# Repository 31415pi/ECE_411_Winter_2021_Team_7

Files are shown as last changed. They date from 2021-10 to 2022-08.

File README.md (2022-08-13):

# ECE411 Sunrise Alarm Clock - Team 7
,
> "Never wake-up in darkness..."

Actual project completion utilized a completely different set of hardware. Updates forthcoming. The Sunrise Alarm Clock is an add on board for an arduino which allows users to interact with an OLED display clock using guestures. The board features 12 RGB SMD LEDs which are used to display time in a meaningful way, indicate confirmation of guesture input, and provide an illuminated alarm experience. A buzzer along with two analog buttons are included to facilitate traditional inputs and alarms if necessary. 

View the [Product Design Specification](./Product%20Design%20Specification%20v1.pdf) for more information.

Look at the [Project Board](https://github.com/31415pi/ECE_411_Winter_2021_Team_7/projects/1).

Schematic located at [Hardware/Schematic](./Hardware/Schematic.pdf).

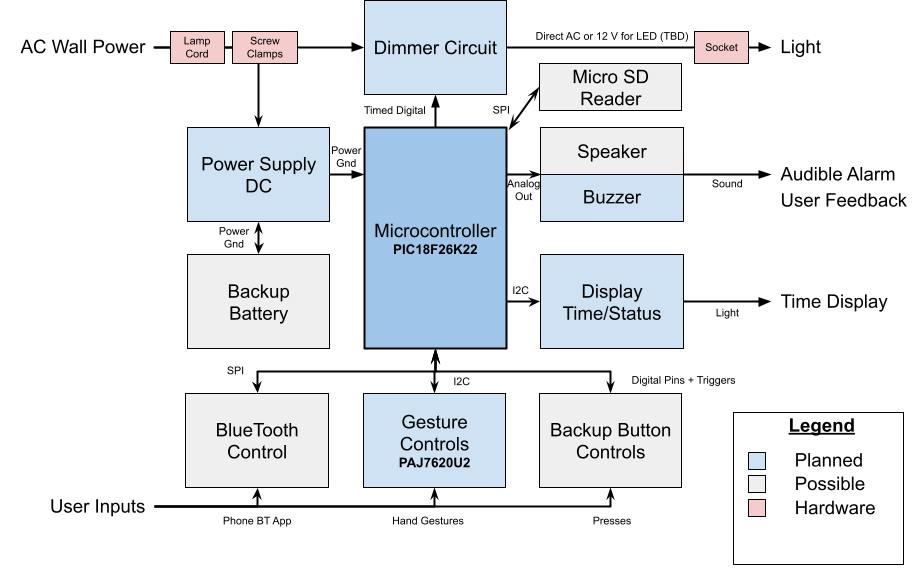
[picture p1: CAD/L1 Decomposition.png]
L1 Decomposition


## Parts List

Parts list on [google drive](https://docs.google.com/spreadsheets/d/1yFu2dnekZCLbKxV9tUKsMTaaS4XpjHtpUTBXEi358RU/edit#gid=0). [Convert to Markdown](https://tabletomarkdown.com/convert-spreadsheet-to-markdown/).

| Part (datasheet link) | Name | Type | Notes | Datasheet | Website | Source | Price  |
| --- | --- | --- | --- | --- | --- | --- | --- |
| [HT16K33](https://github.com/31415pi/ECE_411_Winter_2021_Team_7/blob/main/Datasheets/HT16K33v120(LEDcontroller).pdf) | RAM Mapping 16\*8 LED Controller Driver with keyscan | LED Controller  | | | [https://www.holtek.com/productdetail/-/vg/16K33](https://www.holtek.com/productdetail/-/vg/16K33) | | |
| [PIC18F26K42](https://github.com/31415pi/ECE_411_Winter_2021_Team_7/blob/main/Datasheets/PIC18(L)F26-27-45-46-47-55-56-57K42-Data-Sheet-40001919G.pdf) | | Microcontroller | Actual Model Read from Chip. | [https://www.microchip.com/content/dam/mchp/documents/MCU08/ProductDocuments/DataSheets/PIC18(L)F26-27-45-46-47-55-56-57K42-Data-Sheet-40001919G.pdf](https://www.microchip.com/content/dam/mchp/documents/MCU08/ProductDocuments/DataSheets/PIC18(L)F26-27-45-46-47-55-56-57K42-Data-Sheet-40001919G.pdf) | [https://www.microchip.com/en-us/product/PIC18F26K42](https://www.microchip.com/en-us/product/PIC18F26K42) | EPL | $ 1.50 |
| [IRM-05-5](https://github.com/31415pi/ECE_411_Winter_2021_Team_7/blob/main/Datasheets/IRM-05(ac-5vsupply).pdf) | | DC Power Supply | | | | [Mouser](https://www.mouser.com/ProductDetail/709-IRM05-5) | $ 8.81 |
| [MOC3052TVM](https://github.com/31415pi/ECE_411_Winter_2021_Team_7/blob/main/Datasheets/MOC3052M(ACcont).pdf) | | AC Controller | | | | [Mouser](https://www.mouser.com/ProductDetail/512-MOC3052SR2M)  | $ 1.15 |
| [ACST410-8BTR](https://github.com/31415pi/ECE_411_Winter_2021_Team_7/blob/main/Datasheets/ACST410(ACswitch).pdf) | | AC Switch | | | | [Mouser](https://www.mouser.com/ProductDetail/511-ACST410-8BTR) | $ 0.85 |
| [SFH628A](https://github.com/31415pi/ECE_411_Winter_2021_Team_7/blob/main/Datasheets/SFH628A(ACsensor).pdf) | | AC Sensor | | | | [Mouser](https://www.mouser.com/ProductDetail/782-SFH6286-4T) | $ 1.27 |
| [COM-10931](https://github.com/31415pi/ECE_411_Winter_2021_Team_7/blob/main/Datasheets/COM-10931_ATA3492BW(7seg4digitSparkfun).pdf) | 7-Segment Display - 4-Digit (White) | Time Display | | [http://cdn.sparkfun.com/datasheets/Components/LED/ATA3492BW\_2.pdf](http://cdn.sparkfun.com/datasheets/Components/LED/ATA3492BW_2.pdf) | [https://www.sparkfun.com/products/10931](https://www.sparkfun.com/products/10931) | [Mouser](https://www.mouser.com/ProductDetail/474-COM-10931) | $ 2.63 |

Alternate [Sparkfun Time Display](https://www.sparkfun.com/products/10931).

## Tools

- KiCad. [Third Party Libraries](https://www.kicad.org/libraries/third_party/)
- [Library Loader](https://componentsearchengine.com/tools) for loading schematics into KiCad and others. [Setup Instructions](https://www.samacsys.com/kicad/)

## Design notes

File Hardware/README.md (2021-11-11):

# Hardware Notes

Add libraries to KiCad. <https://www.samacsys.com/kicad/>

## Revisions

### v0.6.1
- Replaces standard button with actual button.

- Added buttons.
- Added AC to Main board connection. Split power lines.
- Corrected non-connected.
- Updated schematic symbols.
- Ran annotations. Components now have numbers.
- Ran ERC check.

### v0.5

- Updated 5v to 3.3v Power Supply.
- Updated Logic control for LED Display.
Use single decoder with V_IH = 1.5v. Works for 1-way control.
- Added a third digit line for alarm and colon.
- Finished buzzer circuit. Tested prototype.
- Corrected Zero Crossing Circuit to be on power line always.
- Corrected Triac Driver resistor to feedback from OUT of power triac.
- Updated symbols.
- AC System Done!
- Added Jumper to Gesture Sensor.
- Tested: Display Works fine with 3.3v. Use Either.
- Added Oscillator
- Added Varistor

### v0.4

- Schematic for LED Display.
- *Noticed LED Display needs 5v!*
- Add PIN assignments.
- Added PIN assignments for gesture sensor.

### v0.3

- Added Gesture Sensor.
- Switch to 3.3v supply. Modified resistors.
- Fix test_led. Added diode.

### v0.2

- Added LED time display.
- Added Buzzer.
- Added Test LED.
- Added Programing Header.

### v0.1

- Added PIC.
- Added AC circuit.
- Added Power supply. Use 5v supply lines.
- Added Rest button.

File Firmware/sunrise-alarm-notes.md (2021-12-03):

# Sunrise Alarm DC

## Evaluation of Screens for Testing

<https://www.amazon.com/Pieces-Display-Module-SSD1306-3-3V-5V/dp/B08CDN5PSJ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>

- Answer on amazon site says that it is not configurable.
- No Manual/Datasheet on amazon website. Reviews say need to Google.
- Best guess based on reviews is that the controller is a clone of the **Adafruit_SSD1306**
    - Link to possible cloned screen. Many configurations so difficult to tell which.
		- Version with i2c only? <https://www.adafruit.com/product/931>
		- Version with SPI only? <https://www.adafruit.com/product/661>
	- Adafruit screens Use onboard jumper to switch i2c address. Have a "D/C" pin fir this reason.
	- Default i2c address: 0x3C
	- Alternate i2c address: 0x3D
	- Some versions are SPI only or I2C only.
	- Link to display [library](https://github.com/adafruit/Adafruit_SSD1306)
	- Links
		- [Tutorial](https://learn.adafruit.com/monochrome-oled-breakouts/downloads)
		- [Datasheet](http://www.adafruit.com/datasheets/SSD1306.pdf)
			- I2c Address "Either “0111100” or “0111101”"

### Conclusions

Unable to switch i2c address on knockoff screen. Since the Adafruit screen uses an additional pin to switch the address no-pin means we are unable to switch. No provided datasheet for the knockoff device means there is no discoverable internal way to swap them. Answers on amazon confirm.

- Possible solution to add a i2c select pin from the Arduino to select which display we are writing to. This may conflict with the internal states of the SSD1306 libraries.

## Search on Mouser for screens

<https://www.mouser.com/c/optoelectronics/displays/oled-displays-accessories/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>

- Options are very expensive.
- Probably more reliable.
- **Out of price range...**

## Evaluation of Maddie's proposed screens

- $6.39 per screen [HiLetgo-Serial-128x64](https://www.amazon.com/HiLetgo-Serial-128X64-Display-Color/dp/B06XRBTBTB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)
	- No selectable address

- $2.80 per screen (bundle of 10) [Frienda-Serial-128x64](https://www.amazon.com/dp/B08VNNCLHD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)
	- I2C address is changeable.
		- Has resistor on the back to select. Resolder to pick address.
	- Default i2c address 0x72
	- Alternate i2c address 0x7A
	- Larger and taller display!

### Conclusion

The Frienda model is a great choice. With both selectable i2c address and a lower cost we would be able to have a large time display with two screens per final product.

- We are able to draw the time large and 
- Low cost!
- Unfortunately no RGB support.

Options on Mouser may be better manufactured and more reliable. However the cheap cost of 10 displays for the same price (or even under) as a oled display on Mouser. The two extra displays should make up for any defects. Hopefully amazon shipping won't let us down.

**tldr;** My suggestion is to go with the Frienda. Use 2 screens per device. If you accept order 1 of devices below.

- [Frienda-Serial-128x64](https://www.amazon.com/dp/B08VNNCLHD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)

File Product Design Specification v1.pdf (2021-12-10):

# Product Design Specification

## Sunrise Alarm Clock - Team 7 Version 1.1

Concept of Operations | 2
Market Analysis | 2
Table 1: Comparison to competition | 3
Requirements | 4
Must | 4
Should | 4
May | 4
System Architecture | 5
Figure 1: L1 Decomposition Block Diagram | 5
Design Specification | 5
Processor - Microcontroller | 5
Sensor - Gesture Control | 5
Power - AC to DC Supply | 5
Actuator - Triac to Light Bulb Socket / DC LED Strip | 5
Actuator - Buzzer/Speaker | 6
Actuator - Seven Segment Display | 6
References | 6

# Version History

Version 1.1 - Removed AC internal components from possibilities. Updated / Removed Requirements.
- Must have easily user-replaceable light. (REMOVED)
- Must be safe. (AC components on separate board) (REMOVED)

Version 1.0 - Initial Document.

# Concept of Operations

The sunrise alarm clock wakes you up by gradually increasing the light in your room. Even in the darkness of Winter, waking up early should be a luminous experience that stimulates your natural circadian rhythm. Our device works to gently wake you up with a gradually brightening light and wake up sound. The light rises in brightness for 30 minutes before the alarm. While the alarm gets gradually louder to use the minimal volume needed to stir you from your slumber. The alarm clock will double as a bedside lamp to make a perfect addition to your home.

Night workers, anyone without an established early rise routine, and those hard of hearing will love using the bright light to knock you awake. While anyone with issues getting up in the morning will love the changes to your natural sleep rhythm. Plus a replaceable standard lightbulb to allow for selecting the perfect lightbulb maximum brightness and color temperature for your individual needs.

“Never start your day with darkness again.” - Team 7

# Market Analysis

While most have switched to using their phones for alarm clocks and many people use bedside lamps for reading and room lighting. McFarlane of the Royal Melbourne Institute of Technology surveyed people 18-60 and showed that 14% use physical alarm clocks [1 p9]. While 84% use phone alarms to wake-up, the market for physical alarms does still exist; by adding features and doubling as a bedside lamp we can penetrate the market. Further, the data in the study show that 92% wakeup to the same audio each day and preferred volume varies greatly [1 p9]. We can conclude that a large adjustable range of volume is needed for the wakeup sounds to meet user preferences. A gradual increase in volume would probably work best to keep all users happy. Below are some other conditions and users that we consider.

- People who are deaf.
- People who don’t want to disturb their partner.
- People who have trouble waking up in the morning (Philip’s studies confirm).
- Night workers and people who rise before the sun.
- Parents of teenagers.

Existing products don’t cover our listed requirements. Philips is the market leader in the tech offering two dimmable clock options. There are many options available by other manufacturers all copying the main features of the philips solution and adding some additional features such as temperature monitoring. Philips hase listed a clinical study of the effectiveness of their product. Confusingly Philips states their brightness in units of LUX which is area dependent. Alternatively a “Gesture & light alarm clock” app exists for Android and iOS that tries to offer the same features. Gesture controlled alarm clock (https://www.indiegogo.com/projects/oboo-the-1st-gesture-controlled-smart-alarm-clock) exists as an Indiegogo campaign but is no longer in production and lacks any dimming features. Philips HUE lights exist and can mimic this wakeup functionality via sync through your phone, but proprietary application and bluetooth protocol is required with little user options and customization and no direct clock features. One product (https://www.aliexpress.com/i/1005002755038746.html)

exists on AliExpress with gesture control and humidity/temperature display; this has no user replaceable bulb.

| Philips SmartSleep HF3520 (https://www.amazon.com/Philips-Simulation-Headspace-Subscription-HF3520/dp/B0093162RM) | Philips SmartSleep HF3650 (https://www.amazon.com/dp/B075S53HD9) | JALL Sunrise Alarm Clock (https://www.amazon.com/Sunrise-Sleepers-Simulation-Nightlight-Daylight/dp/B081CHLF46) | Ours
Cost | $99.99 | $179.95 | $45.98 | TBD
Features | FM radio, tap snooze and automatic dimmable display | midnight lamp, FM radio, phone charging dock, power back-up, speaker, auto dimming display and smart snooze | 2 alarms, FM Radio, 7 Sounds | Gesture Control Auto Dimming Display.
Sounds | 5 Sounds, Radio | 7 Sounds, Radio | 7 Sounds, Radio | User SD Card. Bring your own music, Possible play from phone.
Light, Brightness | 300 Lux, 20 steps, Non-replaceable | 310 Lux, 25 steps, Non-replaceable | 20 steps, Non-replaceable | AC Light bulb. User selectable/ Changeable. Like a lamp.
Power Backup | None | Full | None | Alarm Only

Table 1: Comparison to competition

## Requirements

### Must

- Must have wall socket AC power power.
- Must attempt to wake the user on time.
- Must have control of brightness.
- Must turn off alarm by user interaction
- Must display time
- Must have user set alarm
- Must have basic clock/alarm interactions: Set time. Set Alarm. Cancel Alarm.
- Must have basic lamp features: On, Off, Dimming.

### Should

- Should be intuitive enough to learn controls in 10 minutes.
- Should have backup power (Only for alarm, display)
- Should have physical interaction backup buttons(In case of sensor failure)
- Should keep accurate time within ±5 minutes lost per year
- Should adjust display brightness to light conditions.
- Should have options for light only alarms.
- Should be quiet during operation with suggested lights.

### May

- May support custom audio for wakeup.
- May be configurable via Bluetooth ®
- May have USB power output to charge the phone.
- May have USB data input to connect to the phone for music.
- May have clap on/off sensor.
- May speak with users to guide settings.
- May have a night light feature.

## System Architecture

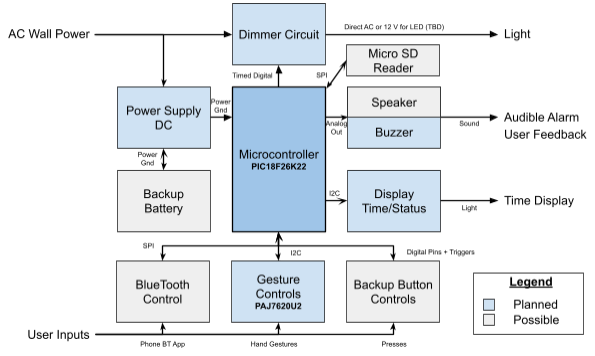
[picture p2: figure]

Figure 1: L1 Decomposition Block Diagram

## Design Specification

### Processor - Microcontroller

PIC18F26K22 (https://www.microchip.com/en-us/product/PIC18F26K22) can be used as the main controller. It has many pins for the various connections we need and is available in the EPL to start prototyping quickly.

### Sensor - Gesture Control

PAJ7620U2 sensor with 9 gestures. Left, Right, Up, Down, Forward, Back, Clockwise, Counterclock wise, and wave. Connect to this by I2C. This is the main control input unit.

### Power - AC to DC Supply

Use prefab AC to 5V Power Supply. Check for safety features. Option is HI-LINK HKL-5M05 for 5V power. May be able to use lower voltage.

### Actuator - Triac to Light Bulb Socket / DC LED Strip

Used for modulating AC voltage based on microcontroller input. Connects to dimmable LED. We will additionally explore using a DC LED strip to produce the desired brightness.

### Actuator - Buzzer/Speaker

Used to create the alarm sound. Controlled with a direct output from the microcontroller.

### Actuator - Seven Segment Display

Used to display time and some configuration settings. Should be dimmable to avoid bright light in darkness. May need a separate controller depending on complexity. https://www.sparkfun.com/products/11441 - With Controller. https://www.sparkfun.com/products/10931 - No Controller (Picked one)

## References

[1] McFarlane SJ, Garcia JE, Verhagen DS, Dyer AG (2020) Alarm tones, music and their elements: Analysis of reported waking sounds to counteract sleep inertia. PLOS ONE 15(1): e0215788. https://doi.org/10.1371/journal.pone.0215788

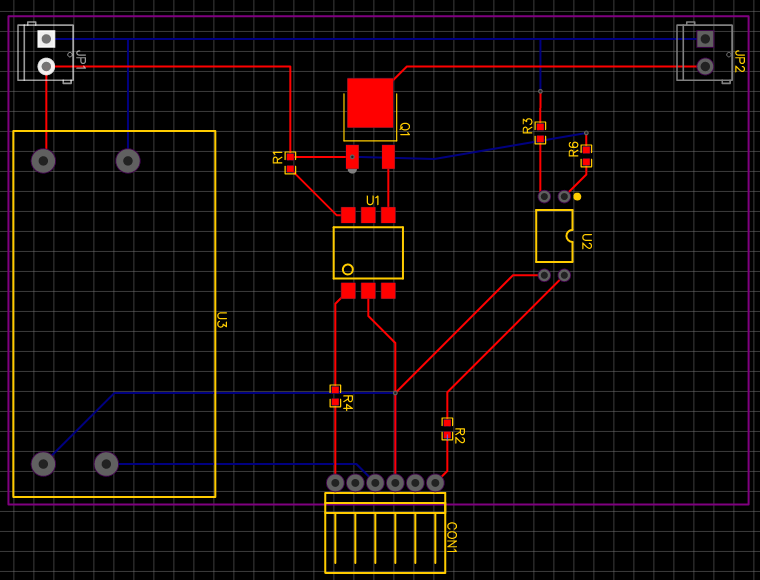
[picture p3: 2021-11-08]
Hardware/Layout AC Sensor,Controller.png

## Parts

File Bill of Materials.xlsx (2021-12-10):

Bill Of Materials for: Team 7 411-Rockstars
Last modified: 2021-10-11
PCB version: v0.1
BOM revision: v0.1 |  | P/NP | = Place/Not Place (components marked NP are not stuffed on the board)
Cnt | Part References | P/NP | Mfg | Mfg PN | Description | Dist | Dist Part Number | Cost Ea. | Cost Total | Name | Website
1 | N/A | NP | DFRobot | SEN0315 | Gesture Sensor Daughterboard (PAJ7620U2) | Mouser | 426-SEN0315 | $8.50 | $8.50
1 | BZ1 | NP | SparkFun Electronics | COM-07950 | SparkFun Accessories Mini Speaker - PC Mount 12mm 2.048kHz | Mouser | 474-COM-07950 (https://www.mouser.com/ProductDetail/474-COM-07950) | $1.95 | $1.95
1 | C1 | P |  |  | 10uF | Mouser |  |  | $0.00
1 | C2 | P |  |  | 10nF | Mouser |  |  | $0.00
1 | C3 | P |  |  | 22uF | Mouser |  |  | $0.00
1 | C4 | P |  |  | 0.1uF | Mouser |  |  | $0.00
1 | D1 | P |  |  | LED | Mouser |  |  | $0.00
1 | D2 | NP | Rectron | 1N5817-T | Diode for inductive kick protection | Mouser | 583-1N5817-T (https://www.mouser.com/ProductDetail/583-1N5817-T) |  | $0.00
1 | IC1 | NP | Texas Instruments | CD74HC237M96 | 3-8 Decoder | Mouser | 595-CD74HC237M96 (https://www.mouser.com/ProductDetail/595-CD74HC237M96) |  | $0.00
1 | IC2 | NP | STMicroelectronics | ACST410-8BTR | AC Power Triac | Mouser | 511-ACST410-8BTR (https://www.mouser.com/ProductDetail/511-ACST410-8BTR) | $0.85 | $0.85
1 | J1 | NP |  | Conn_01x08_Male |  |  |  |  | $0.00
1 | J2 | NP |  | Conn_01x06_Female |  |  |  |  | $0.00
1 | J3 | NP |  | Conn_01x06_Male |  |  |  |  | $0.00
1 | J4 | NP |  | Conn_01x05 |  |  |  |  | $0.00
1 | J6 | NP |  | Conn_Socket | Screw Terminal on Board. Light Socket with screws. |  |  |  | $0.00
1 | JP1 | NP |  | Jumper_2_Bridged |  |  |  |  | $0.00
1 | P1 | NP |  | Conn_WallPlug | Screw Terminal on Board. With Lamp cord to wall. |  |  |  | $0.00
1 | PS1 | NP | MEAN WELL | IRM-05-5 | AC to 5VDC Power Supply | Mouser | 709-IRM05-5 (https://www.mouser.com/ProductDetail/709-IRM05-5) | $8.81 | $8.81
1 | Q1 | NP | Central Semiconductor | 2N3904 PBFREE | Bipolar Transistors - BJT NPN Gen Pur SS | Mouser | 610-2N3904 (https://www.mouser.com/ProductDetail/Central-Semiconductor/2N3904-PBFREE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) | $0.44 | $0.44
2 | R1, R7 | P |  |  | 10K | Mouser |  |  | $0.00
1 | R2 | P |  |  | 200 | Mouser |  |  | $0.00
2 | R3, R4 | P |  |  | 47k | Mouser |  |  | $0.00
2 | R5, R6 | P |  |  | 6.8k | Mouser |  |  | $0.00
1 | R8 | P |  |  | 300 | Mouser |  |  | $0.00
1 | R9 | P |  |  | 100 | Mouser |  |  | $0.00
4 | R10, R11, R12, R13 | P |  |  | 10k | Mouser |  |  | $0.00
2 | R14, R15 | P |  |  | 330 | Mouser |  |  | $0.00
1 | R16 | P |  |  | 80 | Mouser |  |  | $0.00
9 | R17, R19, R20, R21, R22, R23, R24, R25, R26 | P |  |  | 160 | Mouser |  |  | $0.00
1 | R18 | P |  |  | 1k | Mouser |  |  | $0.00
1 | RV1 | NP | Bourns | CV300K14BL1 | Varistor for voltage spike protection | Mouser | 652-CV300K14BL1 (https://www.mouser.com/ProductDetail/652-CV300K14BL1) |  | $0.00
3 | S1, S2, S3 | NP | C&K Switches | PTS526 SK15 SMTR2 LFS | Push Button SMT | Mouser | 611-PTS526SK15SMR2L (https://www.mouser.com/ProductDetail/611-PTS526SK15SMR2L) |  | $0.00
1 | U1 | NP | Diodes Incorporated | AZ1117IH-3.3TRG1 | Power Supply 3.3v | Mouser | 621-AZ1117IH-3.3TRG1 (https://www.mouser.com/ProductDetail/621-AZ1117IH-3.3TRG1) |  | $0.00
1 | U2 | NP | Microchip | PIC18F26K42 | 8-bit Microcontrollers - MCU 64KB Flash, 4KB RAM, 1KB EEPROM | Mouser | 579-PIC18F26K42-I/MX (https://www.mouser.com/ProductDetail/Microchip-Technology/PIC18F26K42-E-SP?qs=HXFqYaX1Q2zsIfQ6qiKPZw%3D%3D) | $2.78 | $2.78
1 | U3 | NP | Vishay | SFH6286-4T | AC Zero Crossing Detector | Mouser | 782-SFH6286-4T (https://www.mouser.com/ProductDetail/782-SFH6286-4T) | $1.27 | $1.27
1 | U4 | NP | onsemi | MOC3052SR2M | AC Power Triac Driver | Mouser | 512-MOC3052SR2M (https://www.mouser.com/ProductDetail/512-MOC3052SR2M) | $1.15 | $1.15
1 | U5 | NP | SparkFun Electronics | COM-10931 | 7-segment 4-digit display with time colon | Mouser | 474-COM-10931 (https://www.mouser.com/ProductDetail/474-COM-10931) | $2.63 | $2.63
1 | Y1 | NP | ABRACON | ASDK-32.768KHz-LRT | Oscillator Crystal | Mouser | 815-ASDK-32.7K-LRT (https://www.mouser.com/ProductDetail/815-ASDK-32.7K-LRT) |  | $0.00
 |  |  |  |  |  |  |  | TOTAL: | $20.55
VERSION INFO
Rev | Date | Notes
1.0r2 |  | Cleaned up formatting.
1.0r1 | 2020-11-06 | Added parts to match order generated from datasheet. Updated AC components to remove any extras. Added totals and summing of cost.
1.0r0 | 2020-11-06 | Initial BOM. Not everything chosen, lots wrong. Mostly just exported from EAGLE.

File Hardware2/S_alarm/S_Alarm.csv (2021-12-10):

Source: | C:\Users\15039\Documents\KiCad\S_alarm\S_Alarm\S_Alarm.kicad_sch
Date: | 11/18/2021 12:05:02 AM
Tool: | Eeschema (5.99.0-13050-gf79cb382c4)
Generator: | C:\Program Files\KiCad\5.99\bin\scripting\plugins/bom_csv_grouped_by_value_with_fp.py
Component Count: | 42
Ref | Qnty | Value | Cmp name | Footprint | Description | Vendor
A1, | 1 | Arduino_UNO_R3 | Arduino_UNO_R3 | Module:Arduino_UNO_R3 | Arduino UNO Microcontroller Module, release 3
BT1, | 1 | Battery_Cell | Battery_Cell | Battery:BatteryHolder_MPD_BC2003_1x2032 | Single-cell battery
BZ1, | 1 | Buzzer | Buzzer | SamacSys_Parts:Buzzer_12x8.5RM6.5 | Buzzer, polarized
C1, | 1 | 10m | C_Small | Capacitor_SMD:C_1206_3216Metric_Pad1.33x1.80mm_HandSolder | Unpolarized capacitor, small symbol
C2, C3, | 2 | 100n | C_Small | Capacitor_SMD:C_1206_3216Metric_Pad1.33x1.80mm_HandSolder | Unpolarized capacitor, small symbol
D1, D3, D4, D5, D6, D8, D9, D10, D11, D13, | 10 | SK6812 | SK6812 | LED_SMD:LED_SK6812_PLCC4_5.0x5.0mm_P3.2mm | RGB LED with integrated controller
D2, | 1 | LED_PWR | LED | LED_SMD:LED_1206_3216Metric_Pad1.42x1.75mm_HandSolder | Light emitting diode
D7, | 1 | LED_PRGRM | LED | LED_SMD:LED_1206_3216Metric_Pad1.42x1.75mm_HandSolder | Light emitting diode
D12, | 1 | LED_BCK_UP_IND | LED | LED_SMD:LED_1206_3216Metric_Pad1.42x1.75mm_HandSolder | Light emitting diode
DS1, | 1 | OLED_LCD_IIC_HH | OLED_LCD_IIC | MODULE
DS2, | 1 | OLED_LCD_IIC_MM | OLED_LCD_IIC | MODULE
Q1, Q2, Q3, Q4, | 4 | Q_NPN_BCE | Q_NPN_BCE | Package_TO_SOT_SMD:SOT-23_Handsoldering | NPN transistor, base/collector/emitter
R1, R2, | 2 | 4.7k | R_US | Resistor_SMD:R_1206_3216Metric_Pad1.30x1.75mm_HandSolder | Resistor, US symbol
R3, R4, | 2 | 220 | R_Small | Resistor_SMD:R_1206_3216Metric_Pad1.30x1.75mm_HandSolder | Resistor, small symbol
R5, R6, R10, R11, R13, | 5 | 1k | R_Small | Resistor_SMD:R_1206_3216Metric_Pad1.30x1.75mm_HandSolder | Resistor, small symbol
R7, | 1 | 110 | R_Small | Resistor_SMD:R_1206_3216Metric_Pad1.30x1.75mm_HandSolder | Resistor, small symbol
R8, R9, | 2 | 10k | R_Small | Resistor_SMD:R_1206_3216Metric_Pad1.30x1.75mm_HandSolder | Resistor, small symbol
R12, | 1 | 170 | R_Small | Resistor_SMD:R_1206_3216Metric_Pad1.30x1.75mm_HandSolder | Resistor, small symbol
SW1, | 1 | SW_Push_ENTER | SW_Push | SamacSys_Parts:PTS526SK15SMTR2LFS | Push button switch, generic, two pins
SW2, | 1 | SW_Push_SEL | SW_Push | SamacSys_Parts:PTS526SK15SMTR2LFS | Push button switch, generic, two pins
U1, | 1 | module_paj7620 | module_paj7620 | usini_sensors:module_paj7620
Y1, | 1 | AB-RTCMC-32.768kHz-B5ZE-S3-T | AB-RTCMC-32.768kHz-B5ZE-S3-T | SamacSys_Parts:ABRTCMC32768kHzB5ZES3T | Real Time Clock HH:MM:SS 12/24 hour Wk DD Alarm/Tmr I2C

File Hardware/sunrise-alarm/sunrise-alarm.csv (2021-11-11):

Source: | C:\Users\Boggy\opt\ece411-sunrise-alarm\Hardware\sunrise-alarm\sunrise-alarm.kicad_sch
Date: | 11/10/2021 11:46:42 PM
Tool: | Eeschema (5.99.0-13086-gffd1139cfe)
Generator: | C:\Program Files\KiCad\5.99\bin\scripting\plugins/bom_csv_grouped_by_value.py
Component Count: | 54
Individual Components:
Item | Qty | Reference(s) | Value | LibPart | Footprint | Datasheet | Arrow Part Number | Arrow Price/Stock | Description | Height | MANUFACTURER | Manufacturer_Name | Manufacturer_Part_Number | Mouser Part Number | Mouser Price/Stock
 |  | BZ1 | Buzzer | Device:Buzzer |  | ~
 |  | C1 | 10u | Device:C_Polarized_Small |  | ~
 |  | C2 | 10nF | Device:C |  | ~
 |  | C3 | 22u | Device:C_Polarized_Small |  | ~
 |  | C4 | 0.1uF | Device:C |  | ~
 |  | D1 | LED | Device:LED |  | ~
 |  | D2 | 1N5817 | Diode:1N5817 | Diode_THT:D_DO-41_SOD81_P10.16mm_Horizontal | http://www.vishay.com/docs/88525/1n5817.pdf
 |  | IC1 | CD74HC237M96 | SamacSys_Parts:CD74HC237M96 | SOIC127P600X175-16N | http://www.ti.com/lit/gpn/cd74hc237 |  |  | Texas Instruments CD74HC237M96, Decoder, Demultiplexer, 1-of-8, Non-Inverting, 2 6 V, 16-Pin SOIC | 1.75 |  | Texas Instruments | CD74HC237M96 | 595-CD74HC237M96 | https://www.mouser.co.uk/ProductDetail/Texas-Instruments/CD74HC237M96?qs=VolsR0DjNPr8qtKYjCpCEA%3D%3D
 |  | IC2 | ACST410-8BTR | Custom:ACST410-8BTR | ACST4108BTR | https://www.st.com/resource/en/datasheet/acst4.pdf | ACST410-8BTR | https://www.arrow.com/en/products/acst410-8btr/stmicroelectronics | STMicroelectronics, ACST410-8BTR, TRIAC, 800V 4A, Gate Trigger 1V 10mA, 3-Pin DPAK | 2.4 |  | STMicroelectronics | ACST410-8BTR | 511-ACST410-8BTR | https://www.mouser.co.uk/ProductDetail/STMicroelectronics/ACST410-8BTR?qs=SAP8%252B8699SA4xcwG%252BvoKnA%3D%3D
 |  | J1 | Conn_01x08_Male | Connector:Conn_01x08_Male |  | ~
 |  | J2 | Conn_01x06_Female | Connector:Conn_01x06_Female |  | ~
 |  | J3 | Conn_01x06_Male | Connector:Conn_01x06_Male |  | ~
 |  | J4 | Conn_01x05 | Connector_Generic:Conn_01x05 | Connector_Harwin:Harwin_M20-89005xx_1x05_P2.54mm_Horizontal | ~
 |  | J6 | Conn_Socket | Connector:Conn_WallSocket |  | ~
 |  | JP1 | Jumper_2_Bridged | Jumper:Jumper_2_Bridged | TestPoint:TestPoint_2Pads_Pitch2.54mm_Drill0.8mm | ~
 |  | P1 | Conn_WallPlug | Connector:Conn_WallPlug |  | ~
 |  | PS1 | IRM-05-5 | Converter_ACDC:IRM-05-5 | Converter_ACDC:Converter_ACDC_MeanWell_IRM-05-xx_THT | https://www.meanwell.com/Upload/PDF/IRM-05/IRM-05-SPEC.PDF
 |  | Q1 | 2N3904 | Transistor_BJT:2N3904 | Package_TO_SOT_THT:TO-92 | https://www.onsemi.com/pub/Collateral/2N3903-D.PDF
 |  | R1 | 10K | Device:R_US |  | ~
 |  | R2 | 200 | Device:R_US |  | ~
 |  | R3 | 47k | Device:R_US |  | ~
 |  | R4 | 47k | Device:R_US |  | ~
 |  | R5 | 6.8k | Device:R_Small |  | ~
 |  | R6 | 6.8k | Device:R_Small |  | ~
 |  | R7 | 10K | Device:R_US |  | ~
 |  | R8 | 300 | Device:R_Small |  | ~
 |  | R9 | 100 | Device:R_US |  | ~
 |  | R10 | 10k | Device:R_Small |  | ~
 |  | R11 | 10k | Device:R_Small |  | ~
 |  | R12 | 10k | Device:R_Small |  | ~
 |  | R13 | 10k | Device:R_Small |  | ~
 |  | R14 | 330 | Device:R_US |  | ~
 |  | R15 | 330 | Device:R_US |  | ~
 |  | R16 | 80 | Device:R_Small |  | ~
 |  | R17 | 160 | Device:R_Small |  | ~
 |  | R18 | 1k | Device:R_Small |  | ~
 |  | R19 | 160 | Device:R_Small |  | ~
 |  | R20 | 160 | Device:R_Small |  | ~
 |  | R21 | 160 | Device:R_Small |  | ~
 |  | R22 | 160 | Device:R_Small |  | ~
 |  | R23 | 160 | Device:R_Small |  | ~
 |  | R24 | 160 | Device:R_Small |  | ~
 |  | R25 | 160 | Device:R_Small |  | ~
 |  | R26 | 160 | Device:R_Small |  | ~
 |  | RV1 | CV300K14BL1 | Device:Varistor |  | ~
 |  | S1 | PTS526_SK15_SMTR2_LFS | Custom:PTS526_SK15_SMTR2_LFS | PTS526SK15SMTR2LFS | https://www.ckswitches.com/media/2780/pts526.pdf |  |  | Tact 5.2 x 5.2, 1.5 mm H, 260gf, G leads, No ground pin, metal actuator | 1.65 |  | C & K COMPONENTS | PTS526 SK15 SMTR2 LFS | 611-PTS526SK15SMR2L | https://www.mouser.co.uk/ProductDetail/CK/PTS526-SK15-SMTR2-LFS?qs=UXgszm6BlbF5Ezp94JAQtw%3D%3D
 |  | S2 | PTS526_SK15_SMTR2_LFS | Custom:PTS526_SK15_SMTR2_LFS | PTS526SK15SMTR2LFS | https://www.ckswitches.com/media/2780/pts526.pdf |  |  | Tact 5.2 x 5.2, 1.5 mm H, 260gf, G leads, No ground pin, metal actuator | 1.65 |  | C & K COMPONENTS | PTS526 SK15 SMTR2 LFS | 611-PTS526SK15SMR2L | https://www.mouser.co.uk/ProductDetail/CK/PTS526-SK15-SMTR2-LFS?qs=UXgszm6BlbF5Ezp94JAQtw%3D%3D
 |  | S3 | PTS526_SK15_SMTR2_LFS | Custom:PTS526_SK15_SMTR2_LFS | PTS526SK15SMTR2LFS | https://www.ckswitches.com/media/2780/pts526.pdf |  |  | Tact 5.2 x 5.2, 1.5 mm H, 260gf, G leads, No ground pin, metal actuator | 1.65 |  | C & K COMPONENTS | PTS526 SK15 SMTR2 LFS | 611-PTS526SK15SMR2L | https://www.mouser.co.uk/ProductDetail/CK/PTS526-SK15-SMTR2-LFS?qs=UXgszm6BlbF5Ezp94JAQtw%3D%3D
 |  | U1 | AZ1117-3.3 | Regulator_Linear:AZ1117-3.3 | Package_TO_SOT_SMD:SOT-89-3_Handsoldering | https://www.diodes.com/assets/Datasheets/AZ1117.pdf
 |  | U2 | PIC18F26K42-xSO | MCU_Microchip_PIC18:PIC18F26K22-xSO | Package_SO:SOIC-28W_7.5x17.9mm_P1.27mm | http://ww1.microchip.com/downloads/en/DeviceDoc/40001412G.pdf
 |  | U3 | SFH6286-4T | Custom:SFH6286-4T | SOIC254P977X460-4N |  |  |  |  |  | Vishay
 |  | U4 | MOC3052M | Relay_SolidState:MOC3052M |  | https://www.onsemi.com/pub/Collateral/MOC3052M-D.PDF
 |  | U5 | COM-10931 | Custom:COM-10931 |  | http://cdn.sparkfun.com/datasheets/Components/LED/ATA3492BW_2.pdf
 |  | Y1 | ASDK-32.768KHZ-LRT | Custom:ASDK-32.768KHZ-LRT | ASDK32768KHZLRT | https://abracon.com/Support/PackageDrawing/Oscillators/ASDK.PDF |  |  | Oscillator XO 0.032768MHz +/-25ppm 15pF CMOS 60% 3.3V 4-Pin SMD T/R | 0.95 |  | ABRACON | ASDK-32.768KHZ-LRT | 815-ASDK-32.7K-LRT | https://www.mouser.co.uk/ProductDetail/ABRACON/ASDK-32768KHz-LRT?qs=iFuT%252BolKbR5RlVqzp84gTQ%3D%3D
Collated Components:
Item | Qty | Reference(s) | Value | LibPart | Footprint | Datasheet | Arrow Part Number | Arrow Price/Stock | Description | Height | MANUFACTURER | Manufacturer_Name | Manufacturer_Part_Number | Mouser Part Number | Mouser Price/Stock
1 | 1 | BZ1 | Buzzer | Device:Buzzer |  | ~
2 | 1 | C1 | 10u | Device:C_Polarized_Small |  | ~
3 | 1 | C2 | 10nF | Device:C |  | ~
4 | 1 | C3 | 22u | Device:C_Polarized_Small |  | ~
5 | 1 | C4 | 0.1uF | Device:C |  | ~
6 | 1 | D1 | LED | Device:LED |  | ~
7 | 1 | D2 | 1N5817 | Diode:1N5817 | Diode_THT:D_DO-41_SOD81_P10.16mm_Horizontal | http://www.vishay.com/docs/88525/1n5817.pdf
8 | 1 | IC1 | CD74HC237M96 | SamacSys_Parts:CD74HC237M96 | SOIC127P600X175-16N | http://www.ti.com/lit/gpn/cd74hc237 |  |  | Texas Instruments CD74HC237M96, Decoder, Demultiplexer, 1-of-8, Non-Inverting, 2 6 V, 16-Pin SOIC | 1.75 |  | Texas Instruments | CD74HC237M96 | 595-CD74HC237M96 | https://www.mouser.co.uk/ProductDetail/Texas-Instruments/CD74HC237M96?qs=VolsR0DjNPr8qtKYjCpCEA%3D%3D
9 | 1 | IC2 | ACST410-8BTR | Custom:ACST410-8BTR | ACST4108BTR | https://www.st.com/resource/en/datasheet/acst4.pdf | ACST410-8BTR | https://www.arrow.com/en/products/acst410-8btr/stmicroelectronics | STMicroelectronics, ACST410-8BTR, TRIAC, 800V 4A, Gate Trigger 1V 10mA, 3-Pin DPAK | 2.4 |  | STMicroelectronics | ACST410-8BTR | 511-ACST410-8BTR | https://www.mouser.co.uk/ProductDetail/STMicroelectronics/ACST410-8BTR?qs=SAP8%252B8699SA4xcwG%252BvoKnA%3D%3D
10 | 1 | J1 | Conn_01x08_Male | Connector:Conn_01x08_Male |  | ~
11 | 1 | J2 | Conn_01x06_Female | Connector:Conn_01x06_Female |  | ~
12 | 1 | J3 | Conn_01x06_Male | Connector:Conn_01x06_Male |  | ~
13 | 1 | J4 | Conn_01x05 | Connector_Generic:Conn_01x05 | Connector_Harwin:Harwin_M20-89005xx_1x05_P2.54mm_Horizontal | ~
14 | 1 | J6 | Conn_Socket | Connector:Conn_WallSocket |  | ~
15 | 1 | JP1 | Jumper_2_Bridged | Jumper:Jumper_2_Bridged | TestPoint:TestPoint_2Pads_Pitch2.54mm_Drill0.8mm | ~
16 | 1 | P1 | Conn_WallPlug | Connector:Conn_WallPlug |  | ~
17 | 1 | PS1 | IRM-05-5 | Converter_ACDC:IRM-05-5 | Converter_ACDC:Converter_ACDC_MeanWell_IRM-05-xx_THT | https://www.meanwell.com/Upload/PDF/IRM-05/IRM-05-SPEC.PDF
18 | 1 | Q1 | 2N3904 | Transistor_BJT:2N3904 | Package_TO_SOT_THT:TO-92 | https://www.onsemi.com/pub/Collateral/2N3903-D.PDF
19 | 2 | R1, R7 | 10K | Device:R_US |  | ~
20 | 1 | R2 | 200 | Device:R_US |  | ~
21 | 2 | R3, R4 | 47k | Device:R_US |  | ~
22 | 2 | R5, R6 | 6.8k | Device:R_Small |  | ~
23 | 1 | R8 | 300 | Device:R_Small |  | ~
24 | 1 | R9 | 100 | Device:R_US |  | ~
25 | 4 | R10, R11, R12, R13 | 10k | Device:R_Small |  | ~
26 | 2 | R14, R15 | 330 | Device:R_US |  | ~
27 | 1 | R16 | 80 | Device:R_Small |  | ~
28 | 9 | R17, R19, R20, R21, R22, R23, R24, R25, R26 | 160 | Device:R_Small |  | ~
29 | 1 | R18 | 1k | Device:R_Small |  | ~
30 | 1 | RV1 | CV300K14BL1 | Device:Varistor |  | ~
31 | 3 | S1, S2, S3 | PTS526_SK15_SMTR2_LFS | Custom:PTS526_SK15_SMTR2_LFS | PTS526SK15SMTR2LFS | https://www.ckswitches.com/media/2780/pts526.pdf |  |  | Tact 5.2 x 5.2, 1.5 mm H, 260gf, G leads, No ground pin, metal actuator | 1.65 |  | C & K COMPONENTS | PTS526 SK15 SMTR2 LFS | 611-PTS526SK15SMR2L | https://www.mouser.co.uk/ProductDetail/CK/PTS526-SK15-SMTR2-LFS?qs=UXgszm6BlbF5Ezp94JAQtw%3D%3D
32 | 1 | U1 | AZ1117-3.3 | Regulator_Linear:AZ1117-3.3 | Package_TO_SOT_SMD:SOT-89-3_Handsoldering | https://www.diodes.com/assets/Datasheets/AZ1117.pdf
33 | 1 | U2 | PIC18F26K42-xSO | MCU_Microchip_PIC18:PIC18F26K22-xSO | Package_SO:SOIC-28W_7.5x17.9mm_P1.27mm | http://ww1.microchip.com/downloads/en/DeviceDoc/40001412G.pdf
34 | 1 | U3 | SFH6286-4T | Custom:SFH6286-4T | SOIC254P977X460-4N |  |  |  |  |  | Vishay
35 | 1 | U4 | MOC3052M | Relay_SolidState:MOC3052M |  | https://www.onsemi.com/pub/Collateral/MOC3052M-D.PDF
36 | 1 | U5 | COM-10931 | Custom:COM-10931 |  | http://cdn.sparkfun.com/datasheets/Components/LED/ATA3492BW_2.pdf
37 | 1 | Y1 | ASDK-32.768KHZ-LRT | Custom:ASDK-32.768KHZ-LRT | ASDK32768KHZLRT | https://abracon.com/Support/PackageDrawing/Oscillators/ASDK.PDF |  |  | Oscillator XO 0.032768MHz +/-25ppm 15pF CMOS 60% 3.3V 4-Pin SMD T/R | 0.95 |  | ABRACON | ASDK-32.768KHZ-LRT | 815-ASDK-32.7K-LRT | https://www.mouser.co.uk/ProductDetail/ABRACON/ASDK-32768KHz-LRT?qs=iFuT%252BolKbR5RlVqzp84gTQ%3D%3D

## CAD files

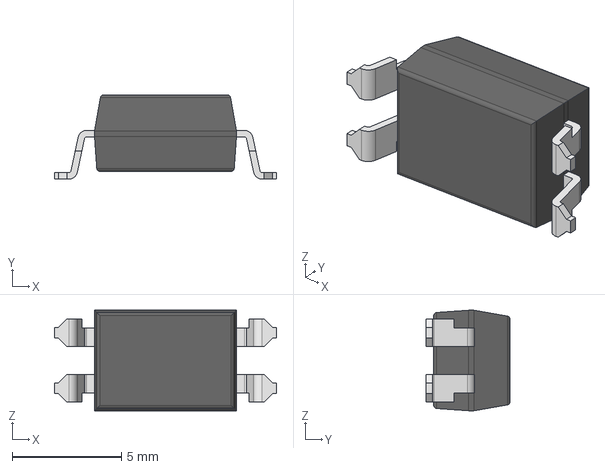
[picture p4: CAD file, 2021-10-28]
Hardware/lib-raw/SFH6286-4T/SFH6286-4T.step
10.2 x 3.85 x 4.60 mm

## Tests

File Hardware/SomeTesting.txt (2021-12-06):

December 5th, 2130 - SAC board testing
[code will not push to arduino with shield connected. probably totally screwed. solution, outside of not having to revamp the entire project in the final hour, add jumpers to all power lines from shield to components, as well as individual data lines to and from components. probably wanted to have tested each thing as it was soldered before moving on to the next solder job.]
[ PINOUT DIAGRAM https://images.prismic.io/circuito/8e3a980f0f964cc539b4cbbba2654bb660db6f52_arduino-uno-pinout-diagram.png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,format ]

[test 00] post -	 	connect power and ensure blink sketch works.
						PASS
[test 01] sw1 - 		SELECT - pin a3 / 12
						test_01.ino - 	
							(0) onboard led glow low. no effect from button push.
						fail
							(1) change to pin 6. no led on power up, no effect from button push.
						fail
							(2) change butoonstate to low from high, initialize to high vs low. [line 45, 31]
						fail
							(3) change pin back to 12.
						fail
							(4) change pin to a3.
						fail
							(5) probed around. switch continuity looks fine. gnd<>gnd, vdd<>vdd looks fine. 
						pass - keep looking
							(6) triple check schmeatic. pin 12 on shield is pin d17/a3 on uno
							(7) change to pin 17. no shield, light on, shield, light off. button press changes nothing. 
						fail
							(8) change to pin a3
						FAIL
							(9) Change button state./ if == low to if == high
						FAIL
							(A) Change to pin 17
						FAIL
							
[test 02] sw2 - 		ENTER 
[test 03] d7 - 			LED_PRGRM - PRG_IND - 25<> D10 
						test_03.ino
							(0) Set to pin 10 Without shield  onboard led is fine. with shield nothing
						FAIL - Potential Short.
							(1) Set to pin 16 Without shield onboard is fine. With shield nothing. 
						FAIL - Likely Short.

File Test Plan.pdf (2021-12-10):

# Test Plan

# Sunrise Alarm Clock - Team 7

## Jana Al-Huneidi Julia Filipchuk Ashlei Brady Maddie Klementyn

Version 1.0

Test Author: Julia Filipchuk
Test Case Name: | Clock Alarm Verification | Test ID #: | 1
Description: | Testing clock and alarm functionality of the clock. - Must turn off alarm by user interaction - Must display time - Must have user set alarm - Must have basic clock/alarm interactions: Set time. Set Alarm. Cancel Alarm. - Must turn off alarm by user interaction | Type: | ☐ white box black box ☐ ________

Tester Information
| Name of Tester: | | Date:
| HW/SW Version: | | Time:
| Setup: | Plug in device. No alarm set. In clock mode.
S T E P | Action | Expected Result | P A S S | F A I L | N / A | Comments
1 | Set Time to 10pm. | Time is adjusted and updated. Continues advancing after change.
2 | Set alarm time for 6am. Enable alarm. | Alarm is adjusted. Alarm enabled signal is showing.
3 | Set Time to 5.55am. | Time is adjusted and updated. Continues advancing after change. Alarm enabled signal is showing. Brightness increases to reflect new 5 minutes until wake.
4 | Wait for alarm. | Alarm triggers when clock reaches 6am. Alarm is audible.
5 | Turn off alarm. | Alarm is stopped with menu gesture.
6
7
8
9
| Overall test result:

Test Author: Julia Filipchuk
Test Case Name: | Brightness Control Verification | Test ID #: | 2
Description: | Testing that we have control of brightness. Step through the full range of brightness of the light. Verify gesture control at all brightness levels. - Must have control of brightness. | Type: | ☐ white box black box ☐ ________

Tester Information
| Name of Tester: | | Date:
| HW/SW Version: | | Time:
| Setup: | Plug in device. No alarm set. In clock mode.
S T E P | Action | Expected Result | P A S S | F A I L | N / A | Comments
1 | Enter Light Mode | Screen is flashing indicating adjustable percent brightness. Start at zero.
2 | Increase the brightness through gestures to max. | Brightness gradually increases proportionally to the percent.
3 | Decrease the brightness through gestures to off. | Brightness gradually decreases proportional to the percent.

4
5
6
7
8
9
| Overall test result:

Test Author: Julia Filipchuk
Test Case Name: | Brightness Alarm Verification | Test ID #: | 3
Description: | Testing that brightness is gradually adjusted before the alarm signal. Verify the alarm can be turned off. - Must have control of brightness. - Must attempt to wake the user on time. - Must turn off alarm by user interaction | Type: | ☐ white box black box ☐ ________

Tester Information
| Name of Tester: | | Date:
| HW/SW Version: | | Time:
| Setup: | Plug in device. No alarm set. In clock mode.
S T E P | Action | Expected Result | P A S S | F A I L | N / A | Comments
1 | Set Alarm gradually increase for 20 minutes. | Adjustment is made in the menu. Back in clock mode after timeout.
2 | Set Time to 5.35am. | Time is adjusted and updated. Continues advancing after change.
3 | Set alarm time for 6am. Enable alarm. | Alarm is adjusted. Alarm enabled signal is showing.
4 | Wait until the alarm triggers. | Monitor gradual brightness increase. Verify sound of alarm at 6.
5 | Turn off alarm. | Alarm is stopped with menu gesture.
6
7
8
9
| Overall test result:

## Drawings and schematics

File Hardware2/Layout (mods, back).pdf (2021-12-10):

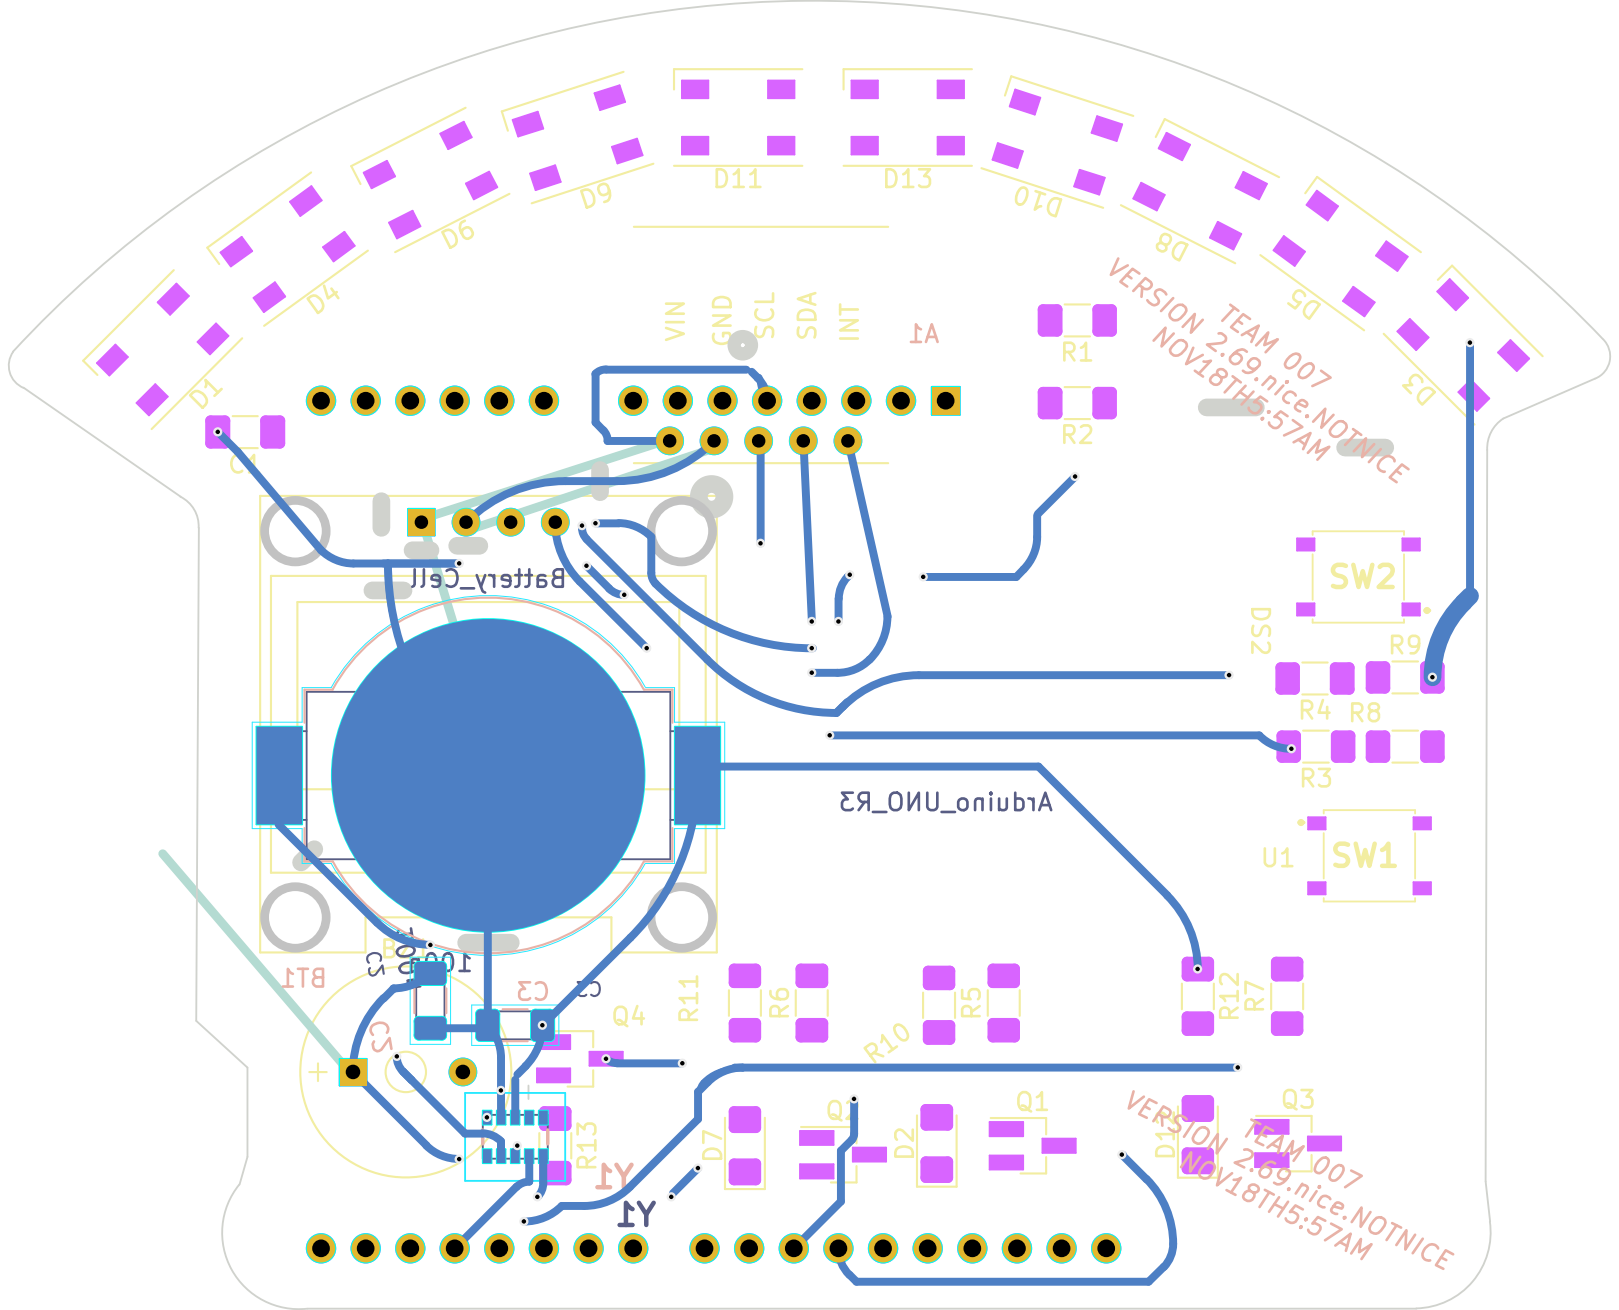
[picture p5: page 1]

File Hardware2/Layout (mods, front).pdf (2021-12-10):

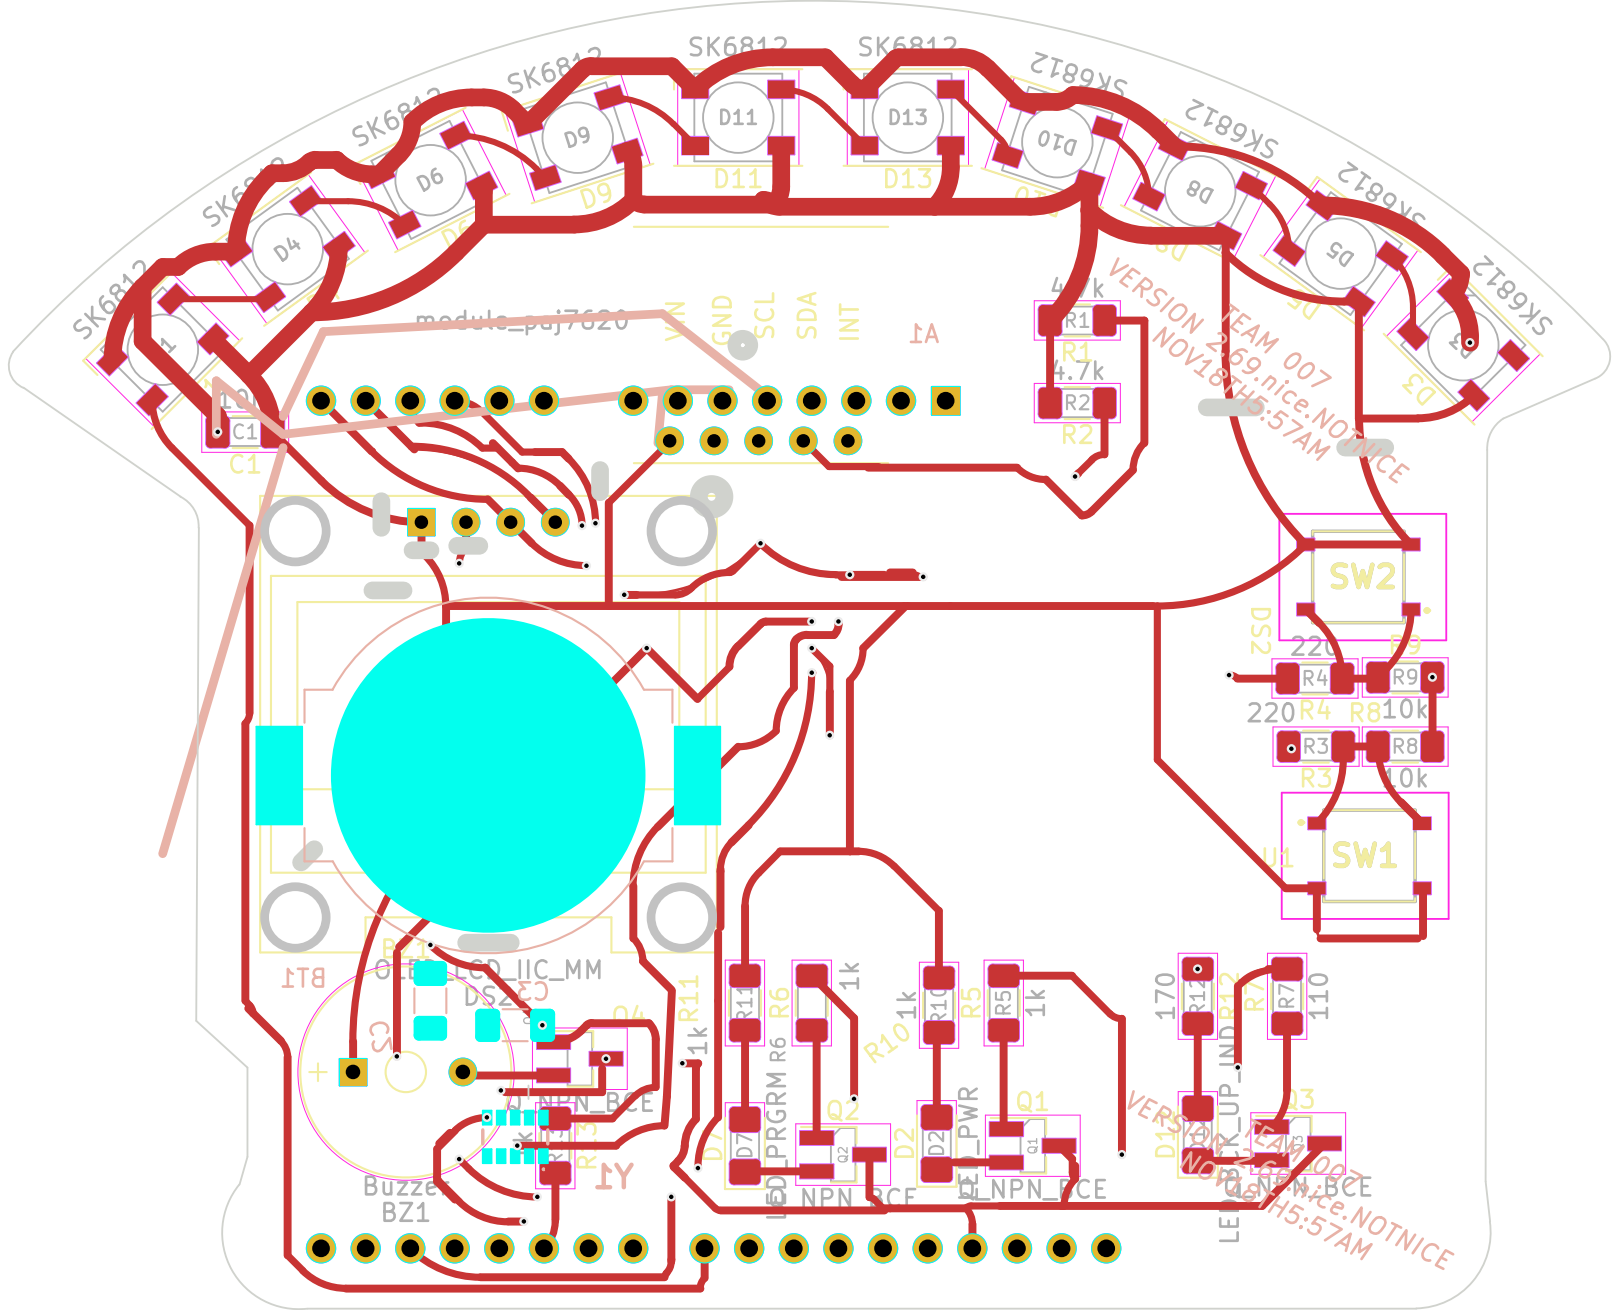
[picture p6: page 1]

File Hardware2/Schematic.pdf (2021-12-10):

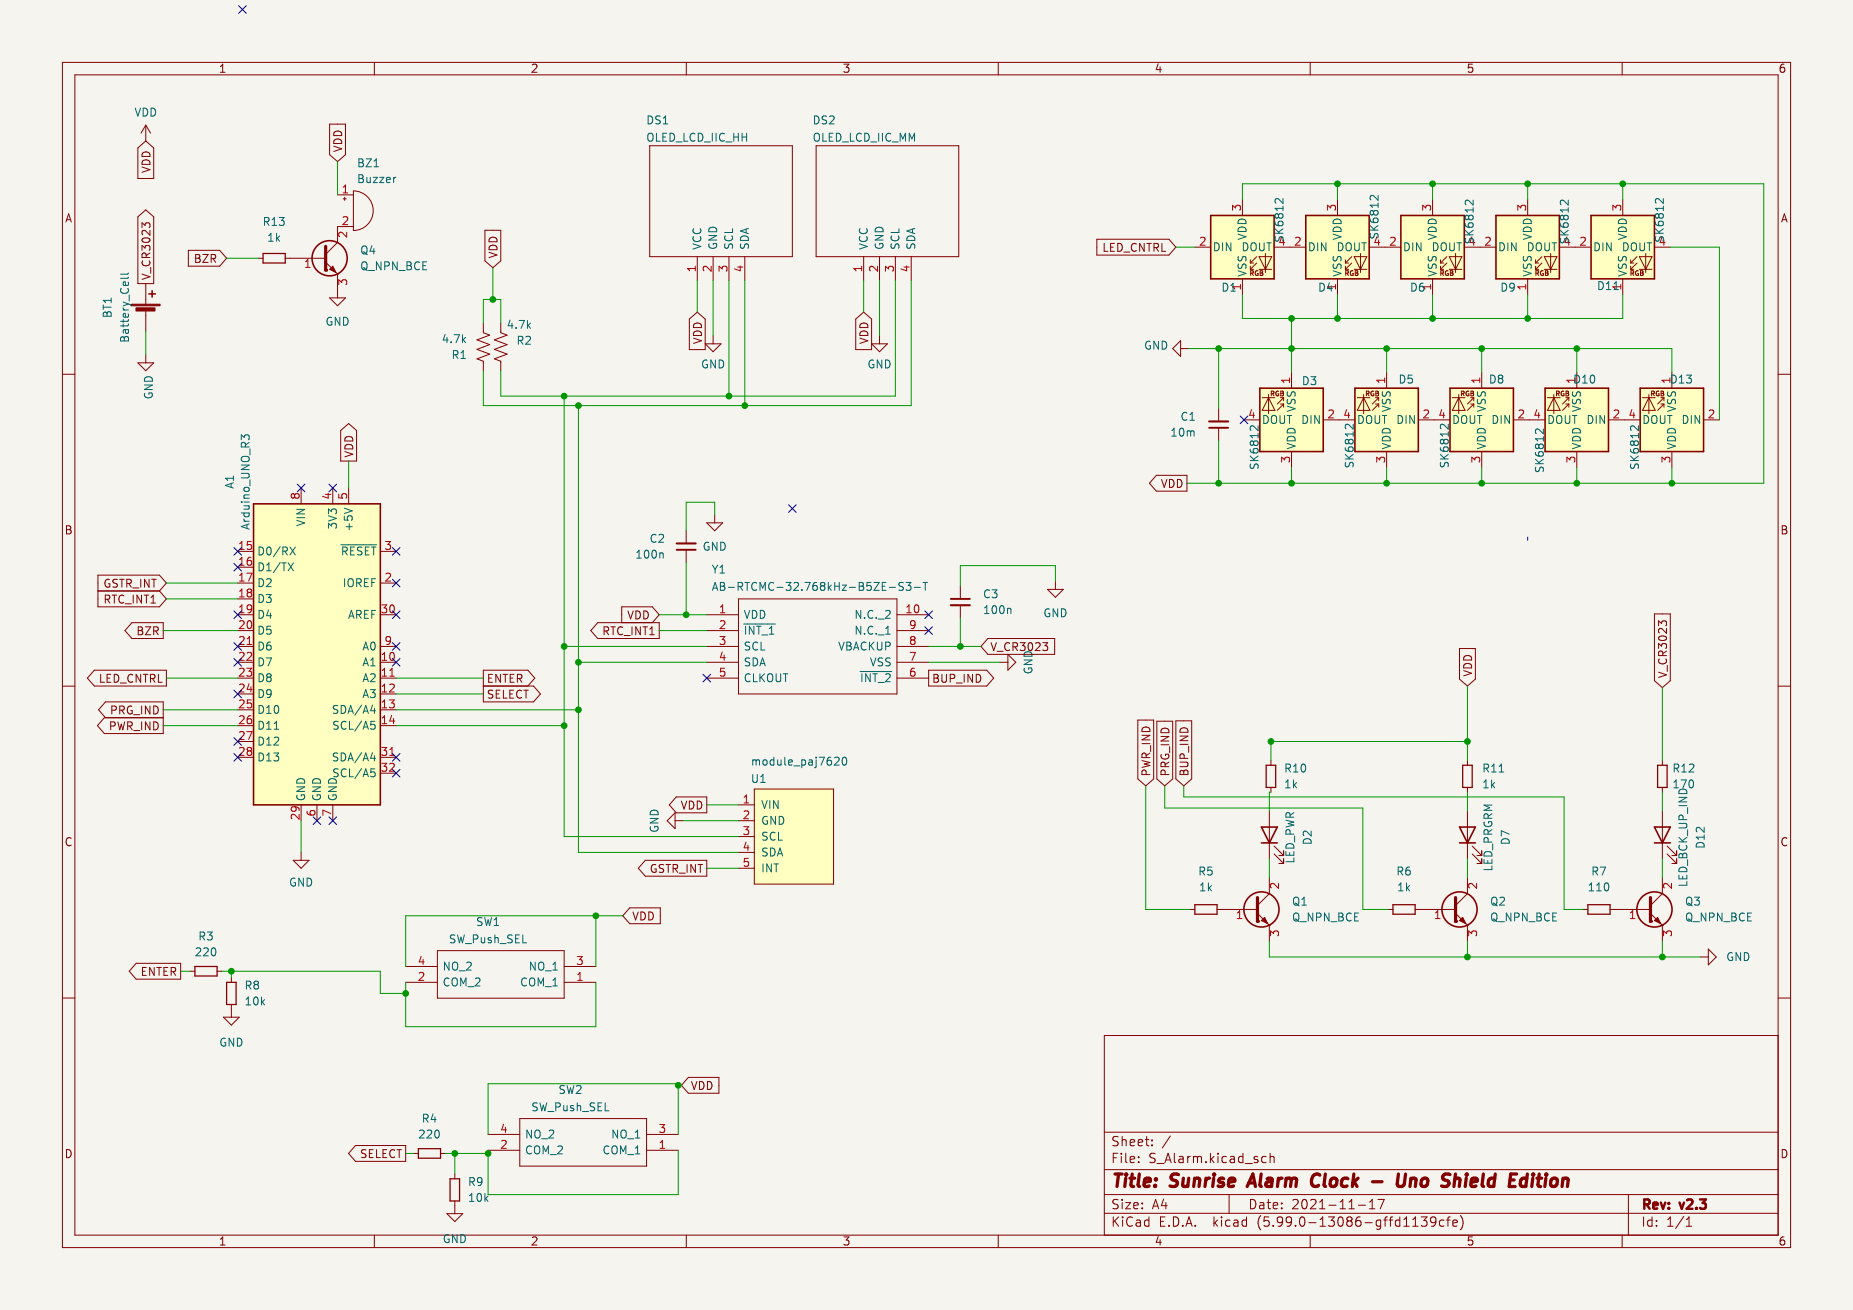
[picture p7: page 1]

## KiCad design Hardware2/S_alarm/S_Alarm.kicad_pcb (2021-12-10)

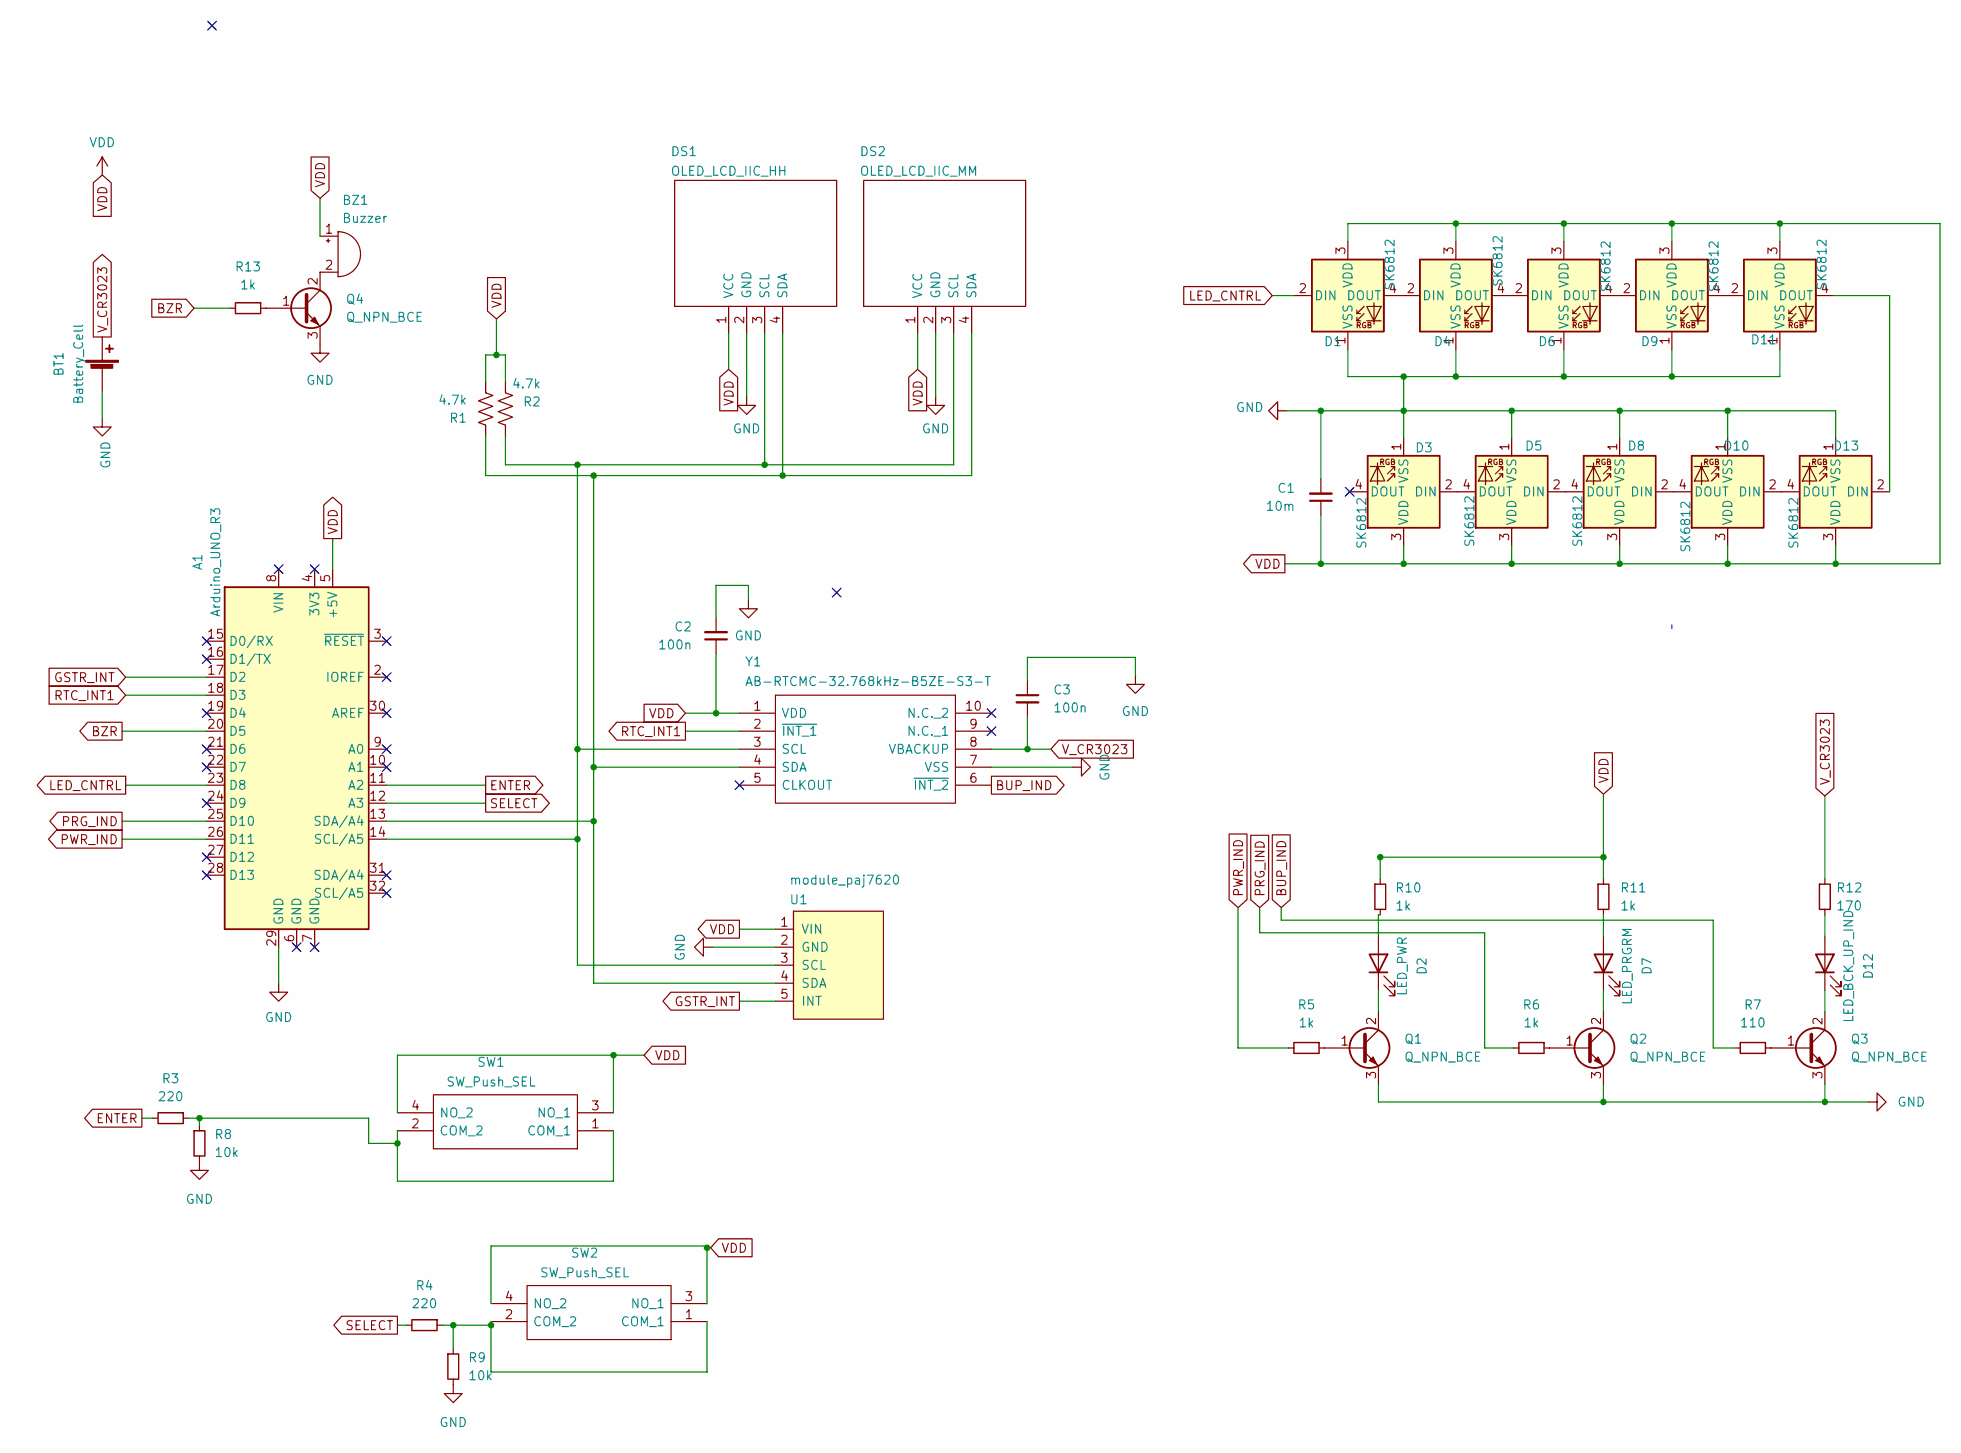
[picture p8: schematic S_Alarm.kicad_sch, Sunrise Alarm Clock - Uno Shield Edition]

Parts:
A1: Arduino_UNO_R3
BT1: Battery_Cell; BatteryHolder_MPD_BC2003_1x2032
BZ1: Buzzer; Buzzer_12x8.5RM6.5
C1: 10m; C_1206_3216Metric_Pad1.33x1.80mm_HandSolder
C2, C3: 100n; C_1206_3216Metric_Pad1.33x1.80mm_HandSolder
D1, D3, D4, D5, D6, D8, D9, D10, D11, D13: SK6812; LED_SK6812_PLCC4_5.0x5.0mm_P3.2mm
D2: LED_PWR; LED_1206_3216Metric_Pad1.42x1.75mm_HandSolder
D7: LED_PRGRM; LED_1206_3216Metric_Pad1.42x1.75mm_HandSolder
D12: LED_BCK_UP_IND; LED_1206_3216Metric_Pad1.42x1.75mm_HandSolder
DS1: OLED_LCD_IIC_HH; Display_OLED_128x64_0.96
DS2: OLED_LCD_IIC_MM; Display_OLED_128x64_0.96
Q1, Q2, Q3, Q4: Q_NPN_BCE; SOT-23_Handsoldering
R1, R2: 4.7k; R_1206_3216Metric_Pad1.30x1.75mm_HandSolder
R3, R4: 220; R_1206_3216Metric_Pad1.30x1.75mm_HandSolder
R5, R6, R10, R11, R13: 1k; R_1206_3216Metric_Pad1.30x1.75mm_HandSolder
R7: 110; R_1206_3216Metric_Pad1.30x1.75mm_HandSolder
R8, R9: 10k; R_1206_3216Metric_Pad1.30x1.75mm_HandSolder
R12: 170; R_1206_3216Metric_Pad1.30x1.75mm_HandSolder
SW1, SW2: SW_Push_SEL; PTS526SK15SMTR2LFS; Mouser Part Number 611-PTS526SK15SMR2L
U1: module_paj7620
Y1: AB-RTCMC-32.768kHz-B5ZE-S3-T; ABRTCMC32768kHzB5ZES3T; Manufacturer_Part_Number AB-RTCMC-32.768kHz-B5ZE-S3-T; Mouser Part Number 815-ABMC-327B5ZES3T

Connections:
BUP_IND: R7.2, Y1.6 (~INT_2)
BZR: A1.20 (D5), R13.2
ENTER: A1.11 (A2), R3.2
GND: A1.29 (GND), BT1.2 (-), C1.2, C2.2, C3.1, D1.1 (VSS), D3.1 (VSS), D4.1 (VSS), D5.1 (VSS), D6.1 (VSS), D8.1 (VSS), D9.1 (VSS), D10.1 (VSS), D11.1 (VSS), D13.1 (VSS), DS1.2 (GND), DS2.2 (GND), Q1.3 (E), Q2.3 (E), Q3.3 (E), Q4.3 (E), R8.2, R9.2, U1.2 (GND), Y1.7 (VSS)
GSTR_INT: A1.17 (D2), U1.5 (INT)
LED_CNTRL: A1.23 (D8), D1.2 (DIN)
unnamed: A1.13 (SDA/A4), DS1.4 (SDA), DS2.4 (SDA), R1.1, U1.4 (SDA), Y1.4 (SDA)
unnamed: A1.14 (SCL/A5), DS1.3 (SCL), DS2.3 (SCL), R2.1, U1.3 (SCL), Y1.3 (SCL)
unnamed: BZ1.2 (+), Q4.2 (C)
unnamed: D1.4 (DOUT), D4.2 (DIN)
unnamed: D2.1 (K), Q1.2 (C)
unnamed: D2.2 (A), R10.2
unnamed: D3.2 (DIN), D5.4 (DOUT)
unnamed: D4.4 (DOUT), D6.2 (DIN)
unnamed: D5.2 (DIN), D8.4 (DOUT)
unnamed: D6.4 (DOUT), D9.2 (DIN)
unnamed: D7.1 (K), Q2.2 (C)
unnamed: D7.2 (A), R11.2
unnamed: D10.2 (DIN), D13.4 (DOUT)
unnamed: D8.2 (DIN), D10.4 (DOUT)
unnamed: D9.4 (DOUT), D11.2 (DIN)
unnamed: D11.4 (DOUT), D13.2 (DIN)
unnamed: D12.1 (K), Q3.2 (C)
unnamed: D12.2 (A), R12.2
unnamed: Q1.1 (B), R5.1
unnamed: Q2.1 (B), R6.1
unnamed: Q3.1 (B), R7.1
unnamed: Q4.1 (B), R13.1
unnamed: R3.1, R8.1, SW1.1 (COM_1), SW1.2 (COM_2)
unnamed: R4.1, R9.1, SW2.1 (COM_1), SW2.2 (COM_2)
PRG_IND: A1.25 (D10), R6.2
PWR_IND: A1.26 (D11), R5.2
RTC_INT1: A1.18 (D3), Y1.2 (~INT_1)
SELECT: A1.12 (A3), R4.2
VDD: A1.5 (+5V), BZ1.1 (-), C1.1, C2.1, D1.3 (VDD), D3.3 (VDD), D4.3 (VDD), D5.3 (VDD), D6.3 (VDD), D8.3 (VDD), D9.3 (VDD), D10.3 (VDD), D11.3 (VDD), D13.3 (VDD), DS1.1 (VCC), DS2.1 (VCC), R1.2, R2.2, R10.1, R11.1, SW1.3 (NO_1), SW1.4 (NO_2), SW2.3 (NO_1), SW2.4 (NO_2), U1.1 (VIN), Y1.1 (VDD)
V_CR3023: BT1.1 (+), C3.2, R12.1, Y1.8 (VBACKUP)

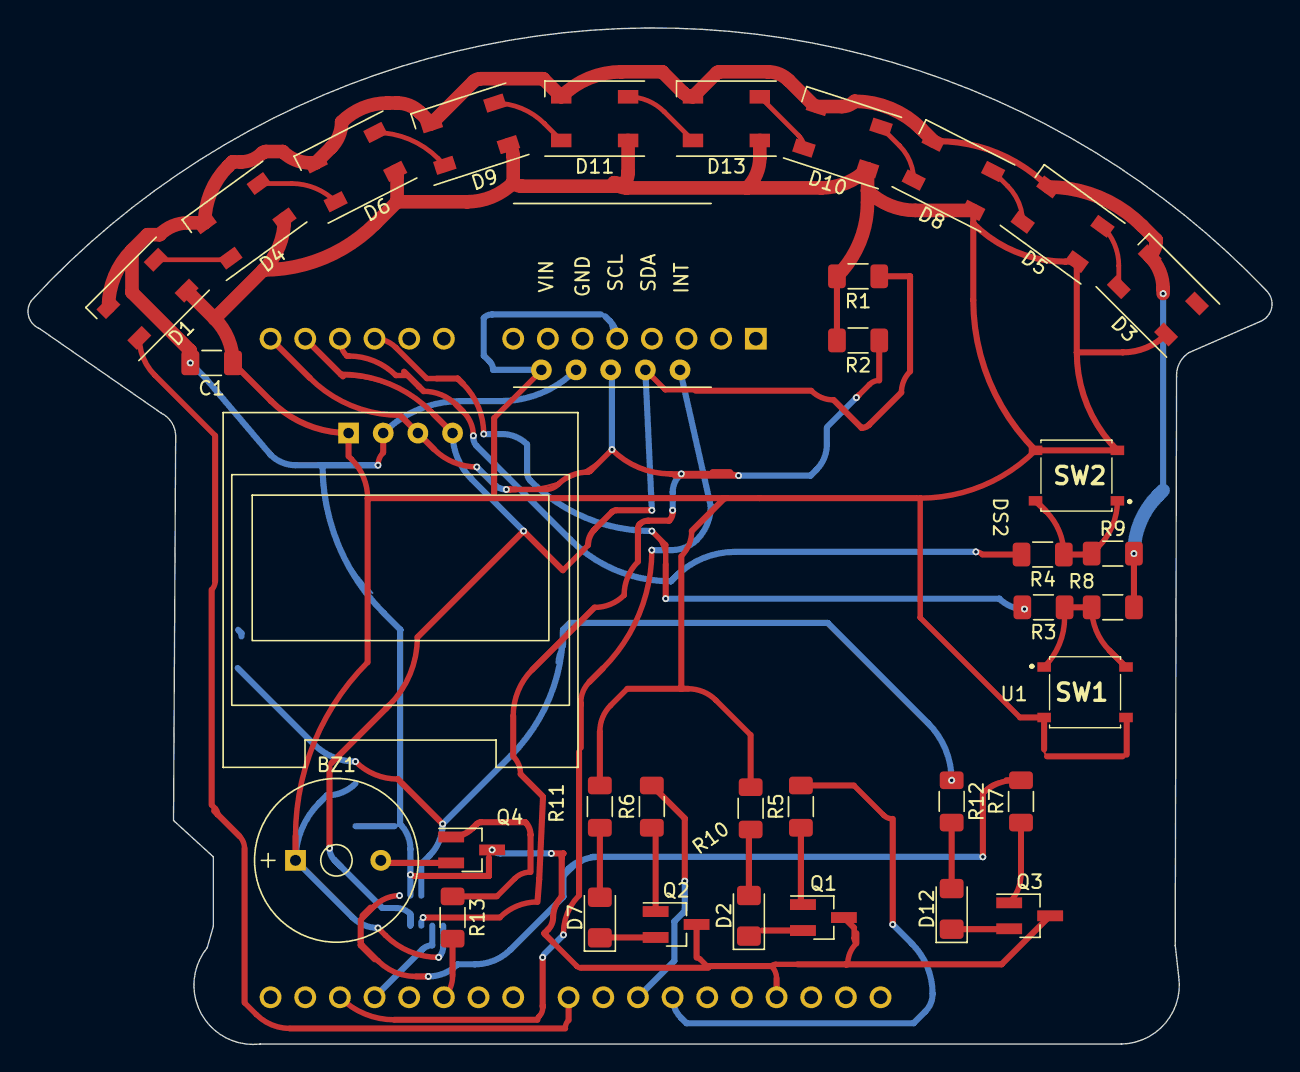
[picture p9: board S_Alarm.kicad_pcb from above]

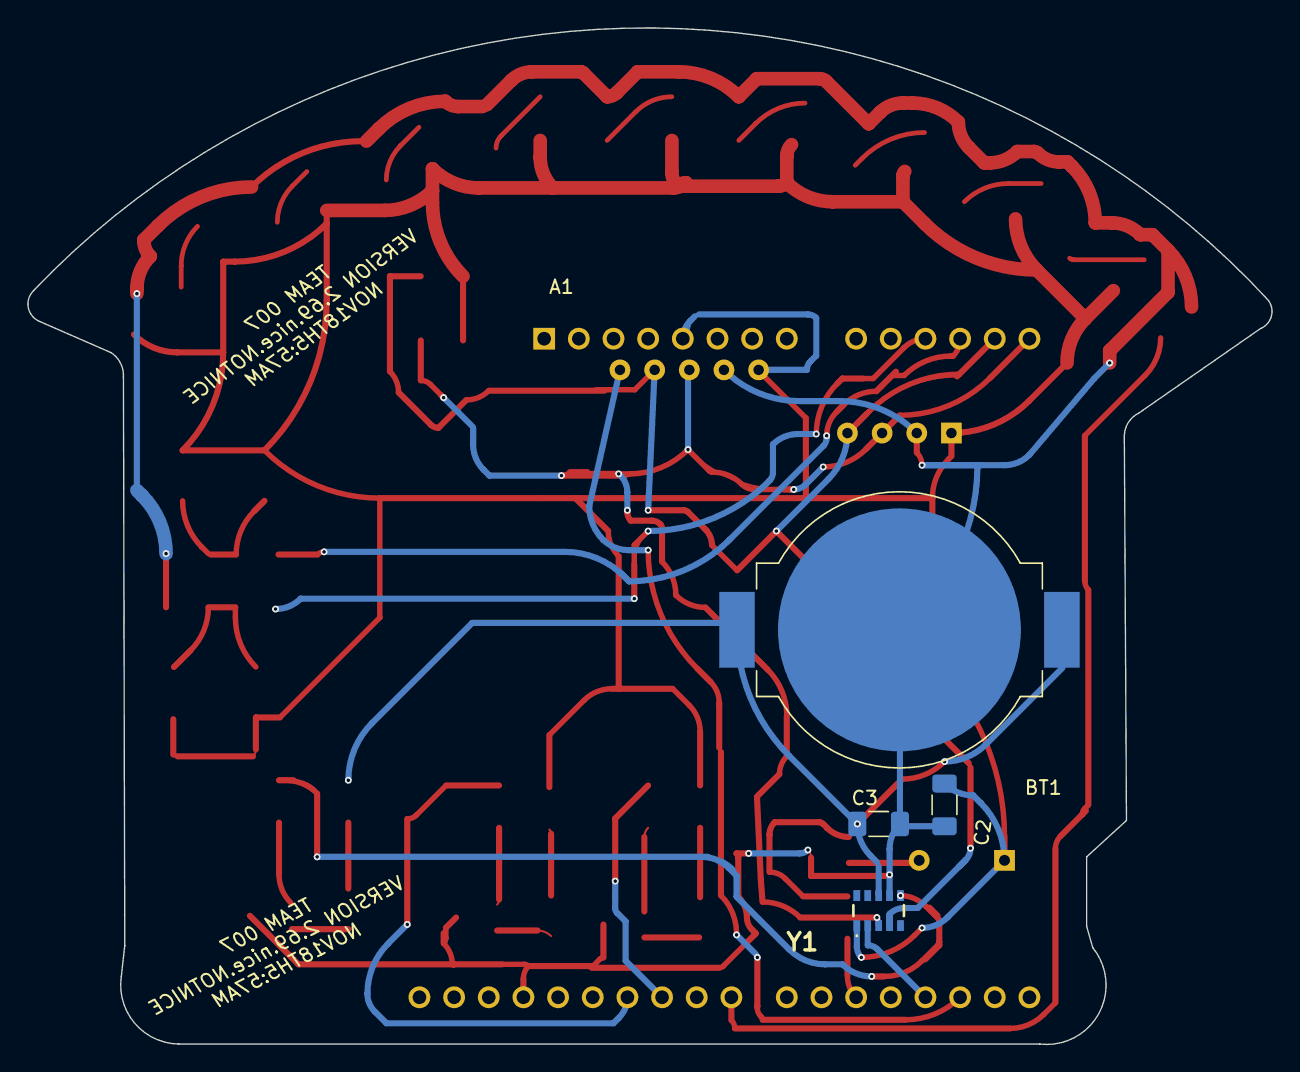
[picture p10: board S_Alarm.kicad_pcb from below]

Board: 2 copper layers, 91.2 x 74.5 mm, 41 parts (5 on the bottom side), 36 nets.

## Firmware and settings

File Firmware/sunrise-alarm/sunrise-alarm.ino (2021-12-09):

// ECE411 Team7 -
//   Julia Filipchuk <bfilipc2@pdx.edu>
//   Maddie Klementyn <muk2@pdx.edu>
//   Jana AlHuneidi <alhuneid@pdx.edu>
//   Ashlei Brady <bashlei@pdx.edu>
// Install Libarries:
//   Adafruit SSD1306 (Use included Custom Version)
//     Adafruit GFX (Intalled as dependency)
//   Adafruit NeoPixel
//   DFRobot PAJ7620U2 (Use included Custom Version)

#include "common.h"

// Pinout
// A4 (SDA), A5 (SCL) pins for I2C comunicaitons.
//const int rtc_interrupt_pin = 2;
//const int paj_interrupt_pin = 3;

int enabled = 0;

void setup() {
  Serial.begin(115200);
 
  gesture_setup();
  control_setup();
  display_setup();
  light_setup();

  // Buttons and Pins
  pinMode(pin_buzzer_pwm, OUTPUT);
  pinMode(pin_button_ent, INPUT);
  pinMode(pin_button_sel, INPUT);
  pinMode(pin_led_prog, OUTPUT);
  pinMode(pin_led_power, OUTPUT);
}

void loop() {
  { // Simulate RTC interrupts.
    static ulong trigger = millis();
    ulong now = millis();
    long diff = now - trigger;
    if (diff >= 0) {
      trigger = now + diff + 1000;
      //control_event(event_tick);
    }
    static ulong ticks = millis();
    if (elapsed(&ticks, 1000))
      control_event(event_tick);
  }

  gesture_service();
  button_service();
  control_service();
  display_service();
  sound_service();
  light_service();
}

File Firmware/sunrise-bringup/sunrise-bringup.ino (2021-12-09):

#include <Adafruit_NeoPixel.h>
#include "common.h"






Adafruit_NeoPixel pixels(cnt_neo_pixels, pin_neo_pixels, NEO_GRB + NEO_KHZ800);

void light_off() {
  log("lights: off");
  ENABLED_CLR(LIGHT);
  pixels.clear();
  pixels.show();
}
void light_on(u08 brightness, u08 r, u08 g, u08 b) {
  log("lights: on");
  ENABLED_SET(LIGHT);
  uint32_t color = pixels.Color(r, g, b);
  pixels.clear();
  pixels.setBrightness(brightness);
  for (int i = 0; i < cnt_neo_pixels; ++i) {
    pixels.setPixelColor(i, color);
    pixels.show();
  }
}
void light_random() {
  log("lights: rand");
  ENABLED_SET(LIGHT);
  uint32_t color = pixels.Color(rand() & 0xFF, rand() & 0xFF, rand() & 0xFF);
  pixels.clear();
  pixels.setBrightness(rand() & 0xFF);
  for (int i = 0; i < cnt_neo_pixels; ++i) {
    pixels.setPixelColor(i, color);
    pixels.show();
  }
}

ulong sound_ticks;
ulong sound_duration;

void sound_off() {
  ENABLED_CLR(SOUND);
  noTone(pin_buzzer_pwm);
}
void sound_chirp() {
  tone(pin_buzzer_pwm, 2000, 1);
}
void sound_bom() {
  tone(pin_buzzer_pwm, 80, 20);
}
void sound_on() {
  ENABLED_SET(SOUND);
  sound_ticks = millis();
  sound_duration = 0;
}
void sound_service() {
  if (ENABLED(SOUND) && elapsed(&sound_ticks, 250)) {
    int note = hz_pentatonic();
    if (note)
      tone(pin_buzzer_pwm, hz_pentatonic(), rythem(250)); 
  }
}


void button_service() {
  static bool enter = 0;
  if (detect_button(&enter, pin_button_ent) == button_pressed) {
    log("enter");
    if (ENABLED(SOUND)) {
      sound_off();
    } else {
      sound_on();
    }
  }
  
  static bool select = 0;
  static ulong select_ticks = 0;
  static int color = 0;
  switch (detect_button_repeat(&select, pin_button_sel, 500, &select_ticks)) {
  case button_pressed:
    light_on(255, 255 * !!(color & 1), 255 * !!(color & 2), 255 * !!(color & 4));
    ++color;
    break;
  case button_released:
    light_off();
    break;
  case button_repeat:
    light_random();
    break;
  }
  if (0 && detect_button_repeat(&select, pin_button_sel, 500, &select_ticks)) {
    log("select");
    if (ENABLED(LIGHT)) {
      light_off();
    } else {
      //light_random();
    }
  }
}

// Globals.
int enabled = 0;

void setup() {
  // put your setup code here, to run once:
  Serial.begin(115200);

  pinMode(pin_buzzer_pwm, OUTPUT);
  pinMode(pin_button_ent, INPUT);
  pinMode(pin_button_sel, INPUT);

  pixels.begin();
  light_off();
  sound_off();
}

void loop() {
  button_service();
  sound_service();
  
  // put your main code here, to run repeatedly:
  static int count = 0;
  static ulong ticks = millis();
  if (elapsed(&ticks, 1000)) {
    log("count: ", ++count);
    //if (count & 1) sound_chirp();
    //else sound_bom();
  }
}

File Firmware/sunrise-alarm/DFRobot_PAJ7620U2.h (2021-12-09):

/*!
 * @file DFRobot_PAJ7620U2.h
 * @brief Define the basic structure of the class DFRobot_PAJ7620 gesture sensor 
 * @n The PAC7620 integrates gesture recognition function with general I2C interface into a single chip forming an image analytic sensor
 * @n system. It can recognize 9 human hand gesticulations such as moving up, down, left, right, forward, backward, circle-clockwise, 
 * @n circle-counter Key Parameters clockwise, and waving. It also offers built-in proximity detection in sensing approaching or
 * @n departing object from the sensor. The PAC7620 is designed with great flexibility in power-saving mechanism, well suit for low 
 * @n power battery operated HMI devices. The PAJ7620 is packaged into module form in-built with IR LED and optics lens as a complete
 * @n sensor solution.
 
 * @copyright   Copyright (c) 2010 DFRobot Co.Ltd (http://www.dfrobot.com)
 * @license     The MIT License (MIT)
 * @author      [Alexander](ouki.wang@dfrobot.com)
 * @maintainer  [fary](feng.yang@dfrobot.com)
 * @version  V1.0
 * @date  2021-10-20
 * @url https://github.com/DFRobot/DFRobot_PAJ7620U2
 */

#ifndef __DFROBOT_PAJ7620U2_H
#define __DFROBOT_PAJ7620U2_H

#include "Arduino.h"
#include <Wire.h>

#define __DFROBOT_PAJ7620U2_H_NO_STRINGS
#define __DFROBOT_PAJ7620U2_H_NO_ARRAY
#define __DFROBOT_PAJ7620U2_H_NO_DEVICE_ADDRESS
//Open this macro to check the detailed running process of the program.
//#define ENABLE_DBG

#ifdef ENABLE_DBG
#define DBG(...) {Serial.print("[");Serial.print(__FUNCTION__); Serial.print("(): "); Serial.print(__LINE__); Serial.print(" ] "); Serial.println(__VA_ARGS__);}
#else
#define DBG(...)
#endif

// DEVICE ID
#define PAJ7620_IIC_ADDR  0x73
#define PAJ7620_PARTID  0x7620

// REGISTER BANK SELECT
#define PAJ7620_REGITER_BANK_SEL  (0xEF)

// REGISTER BANK 0
#define PAJ7620_ADDR_PART_ID_LOW         0x00
#define PAJ7620_ADDR_PART_ID_HIGH        0x01
#define PAJ7620_ADDR_VERSION_ID          0x01
#define PAJ7620_ADDR_SUSPEND_CMD         0x03
#define PAJ7620_ADDR_GES_PS_DET_MASK_0   0x41
#define PAJ7620_ADDR_GES_PS_DET_MASK_1   0x42
#define PAJ7620_ADDR_GES_PS_DET_FLAG_0   0x43
#define PAJ7620_ADDR_GES_PS_DET_FLAG_1   0x44
#define PAJ7620_ADDR_STATE_INDICATOR     0x45
#define PAJ7620_ADDR_PS_HIGH_THRESHOLD   0x69
#define PAJ7620_ADDR_PS_LOW_THRESHOLD    0x6A
#define PAJ7620_ADDR_PS_APPROACH_STATE   0x6B
#define PAJ7620_ADDR_PS_RAW_DATA         0x6C

// REGISTER BANK 1
#define PAJ7620_ADDR_PS_GAIN             0x44
#define PAJ7620_ADDR_IDLE_S1_STEP_0      0x67
#define PAJ7620_ADDR_IDLE_S1_STEP_1      0x68
#define PAJ7620_ADDR_IDLE_S2_STEP_0      0x69
#define PAJ7620_ADDR_IDLE_S2_STEP_1      0x6A
#define PAJ7620_ADDR_OP_TO_S1_STEP_0     0x6B
#define PAJ7620_ADDR_OP_TO_S1_STEP_1     0x6C
#define PAJ7620_ADDR_OP_TO_S2_STEP_0     0x6D
#define PAJ7620_ADDR_OP_TO_S2_STEP_1     0x6E
#define PAJ7620_ADDR_OPERATION_ENABLE    0x72

#define PAJ7620_BANK0 0
#define PAJ7620_BANK1 1

// PAJ7620_ADDR_SUSPEND_CMD
#define PAJ7620_I2C_WAKEUP	0x01
#define PAJ7620_I2C_SUSPEND	0x00

// PAJ7620_ADDR_OPERATION_ENABLE
#define PAJ7620_ENABLE	0x01
#define PAJ7620_DISABLE	0x00

#define GES_REACTION_TIME  50    ///< You can adjust the reaction time according to the actual circumstance.
#define GES_ENTRY_TIME     2000  ///< When you want to recognize the Forward/Backward gestures, your gestures' reaction time must less than GES_ENTRY_TIME(0.8s). 
#define GES_QUIT_TIME      1000 

class DFRobot_PAJ7620U2
{
public:
  #define ERR_OK             0      ///< OK
  #define ERR_DATA_BUS      -1      ///< Error in Data Bus 
  #define ERR_IC_VERSION    -2      ///< IC version mismatch
  /**
   * @enum  eGesture_t
   * @brief gesture information
   */
  typedef enum{
    eGestureNone = 0x00,                                                    /**< no gestures detected */
    eGestureRight = 0x01<<0,                                                /**< move from left to right */
    eGestureLeft  = 0x01<<1,                                                /**< move from right to left */
    eGestureUp    = 0x01<<2,                                                /**< move from down to up */
    eGestureDown  = 0x01<<3,                                                /**< move form up to down */
    eGestureForward   = 0x01<<4,                                            /**< starts far, move close to sensor */
    eGestureBackward  = 0x01<<5,                                            /**< starts near, move far to sensor */
    eGestureClockwise = 0x01<<6,                                            /**< clockwise */
    eGestureAntiClockwise = 0x01<<7,                                        /**< anti-clockwise */
    eGestureWave = 0x01<<8,                                                 /**< wave quickly */
    eGestureWaveSlowlyDisorder = 0x01<<9,                                   /**< wave randomly and slowly */
    eGestureWaveSlowlyLeftRight = eGestureLeft + eGestureRight,             /**< slowly move left and right */
    eGestureWaveSlowlyUpDown = eGestureUp + eGestureDown,                   /**< slowly move up and down */
    eGestureWaveSlowlyForwardBackward = eGestureForward + eGestureBackward, /**< slowly move forward and backward */
    eGestureAll = 0xff                                                      /**< support all gestures, no practical meaning, only suitable for writing abstract program logic. */
  }eGesture_t;
  /**
   * @enum  eBank_t
   * @brief Register Bank
   */
  typedef enum {
    eBank0 = 0, /**< some registers are located in Bank0*/ 
    eBank1 = 1, /**< some registers are located in Bank1*/
  }eBank_t;

  /**
   * @enum  eRateMode_t
   * @brief Gesture Update Rate
   */
  typedef enum {
    eNormalRate = 0, /**< Gesture Update Rate is 120HZ, Gesture speed is 60°/s - 600°/s*/
    eGamingRate = 1, /**< Gesture Update Rate is 240HZ,Gesture speed is 60°/s - 1200°/s*/
  }eRateMode_t;

  /**
   * @struct  sGestureDescription_t
   * @brief Gesture Description
   */
  typedef struct{
    eGesture_t gesture;       /**< Gesture enumeration variable X */
    const char * description; /**< Description about the gesture enumeration variable X */
  }sGestureDescription_t;
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

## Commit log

2021-10-22 Add project board link to readme
2021-10-28 Schematic v0.1 got AC circuit started.
    [SFH6286-4T.step, sunrise-alarm.kicad_pcb, sunrise-alarm.sch]
2021-10-29 Updated schematic, reset button, labeled lines
    [sunrise-alarm.sch]
2021-10-29 Added MPLABX project
    Configured processor registers. Enabled Low Voltage Programing (LVP). Need initial program first.
    Added simple blink code for an LED.
2021-11-04 Schematic: Added programing header
    [sunrise-alarm.sch]
2021-11-04 Schematic: Next Version. Added datasheets
    [SFH6286-4T.step, sunrise-alarm.kicad_sch]
2021-11-04 Remove v5 Schematic. Add LED datasheets.
    [sunrise-alarm.sch]
2021-11-04 Remove v5 Schematic. Add correct LED datasheets.
2021-11-04 Schematic Updates
    Changed to 3.3v supply to accommodate gesture sensor.
    Added gesture sensor.
    Added test led.
    [sunrise-alarm.kicad_sch]
2021-11-04 Schematic: Updated. Fixes
    Added Gesture Sensor.
    Switch to 3.3v supply. Modified resistors.
    Fix test LED.
    Added datasheet.
    [sunrise-alarm.kicad_sch]
2021-11-04 Moved schematic to Firmware. Added link in Readme.
2021-11-05 fw: Reduced programmer voltage to 3.3v for testing
2021-11-05 hw: Added library parts for LED controller, readme
    [sunrise-alarm.kicad_sch]
2021-11-05 hw: Schematic v4. Pin Assignments
    Schematic for LED Display.
    *Noticed LED Display needs 5v!*
    Add PIN assignments.
    Added PIN assignments for gesture sensor.
    Moved Schematic to hardware folder.
    [sunrise-alarm.kicad_sch]
2021-11-08 hw: Added Complete schematic v0.5 + datasheets
    - Updated 5v to 3.3v Power Supply.
    - Updated Logic control for LED Display.
    Use single decoder with V_IH = 1.5v. Works for 1-way control.
    - Added a third digit line for alarm and colon.
    - Finished buzzer circuit. Tested prototype.
    - Corrected Zero Crossing Circuit to be on power line always.
    - Corrected Triac Driver resistor to feedback from OUT of power triac.
    - Updated symbols.
    - AC System Done!
    - Added Jumper to Gesture Sensor.
    - Tested: Display Works fine with 3.3v. Use Either.
    - Added Oscillator
    - Added Varistor
    [sunrise-alarm.kicad_sch]
2021-11-11 Updated Schematic Buttons, Connector, Ran ERC
    - Added buttons.
    - Added AC to Main board connection. Split power lines.
    - Corrected non-connected.
    - Updated schematic symbols.
    - Ran annotations. Components now have numbers.
    - Ran ERC check.
    [sunrise-alarm.kicad_sch]
2021-11-11 Added generated parts list.
    [sunrise-alarm.csv]
2021-11-11 Replaced generic button.
    [sunrise-alarm.csv, sunrise-alarm.kicad_sch]
2021-11-11 Added Bill of Materials.
    [Bill of Materials.xlsx]
2021-12-03 fw: Added Arduino code for gesture sensor
2021-12-09 fw: Corrected time for demo.
    [common.h]
2021-12-10 hw: Added board files from Maddie, schematic printout, mods, docs
    Added missing docs.
    [Bill of Materials.xlsx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]
